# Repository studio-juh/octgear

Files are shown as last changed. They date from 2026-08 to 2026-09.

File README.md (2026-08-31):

# OctGear

RP2040 Zero / compatible boardで動く、8キー + ロータリーエンコーダの小型キーボードです。通常のKeyboard / Consumer Control HIDに加え、WebHIDベースのRemapper、製造検査、ブラウザからのファームウェア更新を提供します。

## Features

- ダイオードなし2 x 4 key matrixと、独立GPIOのロータリーエンコーダCCW / CW / SW
- 8 layers x 11 controlsのキーマップ
- Layer 1-7の個別有効化。Layer 0は常時有効、既定有効はLayer 0/1
- 通常のLayer切り替えは10秒間変化がなければFlashへ保存し、次回起動時に復元
- LayerごとのRGB LED色設定。`0,0,0`で消灯
- Layer色の全灯表示、4灯の点灯パターン、虹色サイクルを切り替えてFlash保存
- 外付けWS2812Bと内蔵mirrorの輝度上限を`0-128`で設定、Flash保存
- 外付けWS2812Bのphysical pixel順を標準／反転で設定、Flash保存
- PCのUSBサスペンド中は外付け・内蔵LEDを消灯
- 打鍵アニメーションを無効／波紋／フラッシュ／スパーク／打鍵虹色から選択、Flash保存
- 通常打鍵は現在Layer色、Layer変更を伴うcontrolは切り替え後のLayer色でアニメーション表示
- Layer表示と独立した打鍵アニメーション輝度上限でコントラストを調整
- Encoder回転方向の反転設定とFlash保存
- PCB v3（Row 1 = GPIO 2）／PCB v2互換（GPIO 0）の切り替えとFlash保存
- Keyboard、Consumer Control、次／前レイヤー、Momentary Layer割り当て
- Next Layerの単押しで次へ進み、同じcontrolのダブルタップで開始位置からPrevious Layerを実行するTap Dance。判定時間は50-1000 msで設定・保存可能（既定250 ms）
- WebHID Remapperによる読込、編集、差分保存
- 物理入力、設定report、Flash保存領域のDiagnostics
- 頒布キット向けの組み立て・Firmware導入・動作確認ガイドと製造データ配布
- WebHIDからのBOOTSEL移行と、同梱UF2の更新
- K1 + K5 + Encoder SWの1秒長押しによる、一時的なWebUSB Remapper案内
- Key 4起動によるREADME drive / Serial rescue。キーマップとdevice設定の確認・変更・初期化に対応

## Web Pages

| Page | Path | Role |
| --- | --- | --- |
| Home | `/` | 製品情報と各ツールへの入口 |
| Start Guide | `/octgear-start.html` | 完成後・完成品購入者向けの導入、設定、サポート案内 |
| Build Guide | `/octgear.html` | 組み立て、Firmware導入、完成検査 |
| Remapper | `/octgear-remapper.html` | キーマップ設定とファームウェア更新 |
| Diagnostics | `/octgear-diagnostics.html` | 出荷前・販売前の個体検査 |

RemapperとDiagnosticsは独立したHTMLとして直接開けます。WebHIDを使うため、対応ブラウザかつsecure contextで実行してください。通常はChromium系ブラウザのHTTPS配信またはlocalhostを想定しています。

## Quick Start

開発環境を初期化します。Arduino CLI、RP2040 core、Arduino librariesはリポジトリ内の`.tools/`と`.arduino/`へ導入されます。

```sh
scripts/setup-dev-env.sh
pnpm dev
```

主な検証・生成コマンド:

```sh
pnpm typecheck          # Web TypeScript
pnpm build              # Web production build
pnpm firmware:build     # Firmware compile
pnpm firmware:web       # Firmware compile + 配信用UF2/RESCUE.CMD/生成日時更新
pnpm hardware:generate  # Hardware profileから3つの生成物を更新
```

初回セットアップと全ビルドをまとめて確認する場合は`scripts/setup-dev-env.sh --verify`を使います。

## Architecture

```text
hardware/octgear/profile.json
        │
        ├─> firmware/.../generated_hardware_config.h
        ├─> apps/web/.../generatedHardwareConfig.ts
        └─> hardware/octgear/pinout.md

Browser ── WebHID config report ──> RP2040 firmware ──> 3-slot Flash journal
   │                                      │
   └─ Remapper / Diagnostics              └─ Keyboard / Consumer HID
```

`hardware/octgear/profile.json`がピン割り当て、コントロール順、レイヤー数の単一ソースです。生成ファイルは直接編集せず、profile変更後に`pnpm hardware:generate`を実行します。Firmware buildでも生成処理は自動実行されます。

詳しいモジュール境界とデータフローは[Architecture](docs/architecture.md)を参照してください。

## Repository Layout

```text
apps/web/                  React + TypeScript + Vite multi-page app
docs/                      横断仕様、開発、運用手順
firmware/octgear/          RP2040 Arduino firmware
hardware/octgear/          Hardware profileと生成pinout
scripts/                   環境構築、生成、firmware build
```

## Hardware Summary

PCB v3を既定とし、RemapperからPCB v2のRow 1配線へ切り替えられます。

現行構成はRow 2本、Column 4本のダイオードなしkey matrixと、A/Common/B/SWを独立GPIOへ接続するロータリーエンコーダです。ダイオードがないため、一部の矩形同時押しは電気的に区別できません。Firmwareは曖昧な間のMatrix状態を更新せず、phantom keyの出力を防ぎます。正確なGPIOは生成された[pinout](hardware/octgear/pinout.md)を参照してください。

通常起動中にK1、K5、Encoder SWを同時に1秒間押すと、LEDが水色に光って再起動し、その起動だけWebUSBのRemapper案内を有効にします。対応するdesktop Chromiumでは接続通知からRemapperを開けます。次回の再起動では通常のUSB構成へ戻ります。

Key 4を押しながらUSB接続すると、その起動だけread-onlyの`OCTGEAR`ドライブとSerial rescueが有効になります。通常起動では表示されません。詳しい操作と復旧手順は[Operations](docs/operations.md)にあります。

## USB Identity

| Field | Default |
| --- | --- |
| Vendor ID | `0x2E8A` |
| Product ID | `0x1133` |
| Manufacturer | `OctGear` |
| Product | `OctGear` |

`0x2E8A:0x1133`は[Raspberry Pi USB PID program](https://github.com/raspberrypi/usb-pid)からOctGear向けに割り当てられたidentityです。Firmware build defaultsとWeb側の接続filterで同じ値を使用します。Forkや別製品ではこの組み合わせを流用せず、各製品で使用許可を得たUSB identityへ置き換えてください。

## Documentation

| Document | 内容 |
| --- | --- |
| [Documentation Index](docs/index.md) | 目的別の文書案内と更新条件 |
| [Architecture](docs/architecture.md) | システム構成、責務、実行時データフロー |
| [Development](docs/development.md) | 環境構築、コマンド、変更別ワークフロー |
| [Operations](docs/operations.md) | Remapper、更新、Diagnostics、Serial rescue |
| [HID Report Protocol](docs/hid-report.md) | WebHID vendor reportのwire format |
| [Cost Estimate](docs/cost-estimate.md) | 少量頒布時の暫定材料原価と梱包条件 |
| [AI Context](docs/ai-context.md) | AI向けのproject map、正本、領域間契約 |
| [Agent Guide](AGENTS.md) | AI agentの作業規約と検証checklist |
| [Web App](apps/web/README.md) | Webアプリ内部の構成 |
| [Firmware](firmware/octgear/README.md) | Firmwareの構成とbuild |
| [Hardware](hardware/octgear/README.md) | Hardware profileと生成物 |

## Distribution And Contact

OctGearの主要頒布先と問い合わせ窓口は[BOOTHショップ](https://hanairo-m.booth.pm/)です。

## Project Policy

OctGearは個人プロジェクトとして管理しています。IssueやPull Requestは送信できますが、確認、返信、レビュー、マージ、対応時期は保証しません。対応まで長期間かかる場合や、対応しない場合があります。必要に応じてForkし、各Forkで管理してください。

## License

Copyright 2026 falxala

Software and software documentation are licensed under the [Apache License 2.0](LICENSE).

`hardware/`以下のhardware design materialsは[OctGear Hardware License 1.0](HARDWARE-LICENSE.md)の対象です。個人による非商用の自作は許可されますが、基準となるハードウェア構成を実質的に変更せず製造・販売することは禁止されています。このため、リポジトリ全体をOSI準拠のオープンソースとして提供するものではありません。

名称、ロゴ、公式性の表示については[Trademark Policy](TRADEMARKS.md)を参照してください。

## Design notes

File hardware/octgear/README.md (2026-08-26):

# OctGear Hardware

The materials in this directory are provided under the [OctGear Hardware License 1.0](../../HARDWARE-LICENSE.md). Personal, non-commercial builds are permitted. Commercial manufacture or sale of the reference hardware without material hardware changes is prohibited.

現行2 x 4 key matrix + rotary encoder版のhardware metadataです。PCB v3を既定とし、同じFirmwareからPCB v2のRow 1配線へ切り替える互換情報も管理します。PCB designそのものではなく、firmwareとWeb UIが共有するlogical control、matrix pin mapping、layer count、default enabled layers、default layer colors、Layer / 打鍵アニメーション輝度既定値 / 上限、打鍵アニメーション既定値、外付けWS2812B GPIO / pixel count / 既定方向を管理します。

## Files

| File | Ownership |
| --- | --- |
| `profile.json` | 手動編集するsingle source of truth |
| `pinout.md` | profileから生成する人向けpin table |
| `../../apps/web/public/build-guide/pcb/` | Build Guide掲載用のPCB製造preview |
| `../../apps/web/public/build-guide/downloads/` | 頒布用Gerber ZIPとcase / knob STL |

同じprofileから次も生成します。

- `firmware/octgear/octgear/generated_hardware_config.h`
- `apps/web/src/products/octgear/generatedHardwareConfig.ts`

## Change Workflow

1. `profile.json`を編集します。
2. Repository rootで`pnpm hardware:generate`を実行します。
3. 3つの生成物のdiffを確認します。
4. Webとfirmwareをbuildします。

```sh
pnpm hardware:generate
pnpm build
pnpm firmware:build
```

Generated filesは直接編集しません。Generatorはindex順とencoder control IDを検証し、不整合時は失敗します。

PCB preview、Gerber、STLはgenerator対象ではありません。製造データを更新した場合はBuild Guideの表示とdownload linkを確認し、Gerber ZIP内のprefixも`octgear-`へ揃えます。

## Electrical Assumptions

- 2 Row x 4 Columnのmatrixで、ダイオードは使用しない
- Columnは`INPUT_PULLUP`、scan対象Rowだけを`OUTPUT LOW`にする
- PCB v3のRow 1はGPIO 2、PCB v2互換のRow 1はGPIO 0。Remapperからrevision単位で切り替え、任意GPIOは指定させない
- ダイオードがないため矩形同時押しは区別できず、Firmwareは曖昧な間のMatrix状態を保持する
- Encoder A/B/SWは`INPUT_PULLUP`、専用Common GPIOは常時`OUTPUT LOW`
- External WS2812Bのdata inputはGPIO 14へ接続し、4 pixels分のdataを送る
- 打鍵アニメーションはmatrixの各columnをLED 1〜4へ対応させ、EncoderのCCW / CW / SWは右端のLED 4をK4 / K8と共有する
- Layer表示は全灯と、4灯の点灯パターンによる8状態をRemapperから切り替えられる
- Status表示は外付けWS2812Bへ出力し、対応boardではonboard WS2812にもミラーする
- LED拡散部品は側面LEDの光を外周へ通す構造のため、透明または半透明の造形素材を推奨する
- OLEDは使用しない
- Key 4は通常inputとrescue boot triggerを兼用

現在のGPIOとfirmware indexは[`pinout.md`](pinout.md)を参照してください。Data flowと影響範囲は[`docs/architecture.md`](../../docs/architecture.md)にあります。

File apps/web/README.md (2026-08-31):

# Web App

React 19 + TypeScript + Viteで構成する、OctGearのWeb toolsです。Home、Start Guide、Build Guide、Remapper、Diagnosticsと、非リンクの印刷用ページをmulti-page buildで出力します。

システム全体の関係は[`docs/architecture.md`](../../docs/architecture.md)、利用手順は[`docs/operations.md`](../../docs/operations.md)を参照してください。

## Entry Points

| Page | HTML | React entry | Page component |
| --- | --- | --- | --- |
| Home | `index.html` | `src/main.tsx` | `src/app/pages/HomePage.tsx` |
| Start Guide | `octgear-start.html` | `src/pages/start-guide.tsx` | `src/app/pages/StartGuidePage.tsx` |
| Start Guide A6 Card | `octgear-start-card-a6.html` | Static HTML | 非リンク・`noindex`の同梱カード印刷用ページ |
| Build Guide | `octgear.html` | `src/pages/build-guide.tsx` | `src/app/pages/BuildGuidePage.tsx` |
| Remapper | `octgear-remapper.html` | `src/pages/remapper.tsx` | `src/app/pages/RemapperApp.tsx` |
| Diagnostics | `octgear-diagnostics.html` | `src/pages/diagnostics.tsx` | `src/app/pages/DiagnosticsApp.tsx` |

GitHub Pages modeではVite baseが`/octgear/`、通常のdevelopment / buildでは`/`です。内部linkとfirmware asset URLはbaseを考慮して組み立てます。

## Source Layout

```text
src/
├── app/
│   ├── components/       pageを構成するUI
│   ├── hooks/            device session lifecycle
│   ├── pages/            page-level stateとworkflow
│   └── remapper/         editor固有の変換
├── features/
│   ├── device/           WebHID transportとcommand codec
│   ├── firmware/         UF2 download / install
│   ├── hardware/         製品共通hardware metadata型
│   └── keymap/           assignment modelとpicker data
├── pages/                multi-page entry points
├── products/             製品定義、製品一覧、製品別generated metadata
└── shared/               i18n等の小さい共通module
```

Dependency directionはpageからfeatureへ向けます。TransportはUI stateを持たず、protocol moduleはDOMを参照しません。特定featureだけで使う処理は`shared`へ移さず、そのfeature内に置きます。

## Product Definitions

`src/products/<product-id>/product.ts`がWeb側の製品単位の正本です。製品名、page route、公式頒布・問い合わせ先、markとBuild Guide asset、USB VID/PID、配布UF2、生成Hardware metadataを1つの`ProductDefinition`へまとめます。Homeは`src/products/catalog.ts`を`ProductCard`で描画し、Remapper、Diagnostics、Build Guideは各entry pointから`ProductProvider`で対象製品を受け取ります。共通のWebHID transportとFirmware updaterは製品固有値を保持しません。

対応製品を追加する場合:

1. `hardware/<product-id>/profile.json`と対応Firmware directoryを用意し、`node scripts/generate-hardware-config.mjs <product-id>`を実行します。
2. `src/products/<product-id>/product.ts`へroute、asset、USB identity、UF2を定義し、`catalog.ts`へ追加します。
3. `ja.ts`と`en.ts`へ製品文言を追加し、`productMessages.ts`で製品IDへ対応づけます。
4. 製品別HTMLと`src/pages/` entryを追加し、`ProductProvider`へ製品定義を渡してVite inputへ登録します。
5. Build Guide assetと配布UF2を製品定義のpublic pathへ配置します。

RemapperとDiagnosticsの共通利用には現在の32-byte WebHID protocolとの互換性が必要です。protocolが異なる製品はtransport / command adapterも製品定義から切り替えられる境界を追加してください。

HomeのOctGear product cardは`public/build-guide/completed/`の正面写真を製品visualとして使用します。Build Guideの完成配置図は`public/build-guide/layout/`のSVG外形へHTML / CSSの8キー、Encoder、側面4灯を重ね、同directoryの完成写真と`public/build-guide/pcb/`のPCB製造previewを併記します。写真とpreviewはページ内で拡大表示できます。部品識別と組み立て工程の写真は`public/build-guide/assembly/`へ配置し、`ja.ts`と`en.ts`の各`photo.file`へfile名を設定するとプレースホルダーから写真表示へ切り替わります。Three.jsのSTL Viewerではケース上面・底面、LED拡散部品、Encoderノブ、ゴム足固定ジグをbrowser内で読み込み、回転・zoom・表示resetを提供します。組み立て、製造データdownload、Firmware導入、Diagnosticsによる完成検査を1ページで案内し、印刷時はnavigationとWeb操作buttonを省略します。

配布用GerberとSTLは`public/build-guide/downloads/`で管理します。公開名には製品名と部品用途を含め、Gerber ZIP内のfile prefixも`octgear-`へ統一します。

## Device Session

接続時は次の順で処理します。

1. 対象entry pointへ渡された製品定義のVID/PID filterでdeviceを選択
2. HID deviceをopen
3. heartbeatを送信
4. `GetState`でdevice dimensions、layer状態、PCBリビジョン、Encoder方向、LEDテープ方向、Layer表示モード、打鍵アニメーションと輝度上限、Tap Dance判定時間を取得
5. `GetKey`で全keymapを読込
6. 300 ms間隔のheartbeatとphysical disconnect listenerを開始

Webは現行Firmwareの14-byte `GetState`と全設定commandを必須契約として扱います。過去Firmware向けの短いresponse、未対応command、Layer色fallbackは受け入れません。

Heartbeat sendが失敗するか700 msでtimeoutするとsessionを閉じます。Firmware側のheartbeat有効期限は3000 msです。

WebHID commandは固定32-byte reportです。同期requestは同じcommand byteのresponseを1つ待つ設計なので、同じtransport上でcommandを並列送信しないでください。詳細は[`docs/hid-report.md`](../../docs/hid-report.md)にあります。

## Remapper State

Remapperは2つのkeymapを保持します。

- `readKeymap`: 最後にdeviceから正常に読んだ内容
- `writeKeymap`: UIで編集中の内容

Layerの有効状態とRGB LED色も読込済みと編集中で分けて保持します。Layer 0は常時有効で、Layer 1-7はcheckboxから変更できます。初期状態ではLayer 0と1だけが有効です。RGB `0,0,0`は消灯として扱います。

Save時はdeviceが返したlayer / key countへnormalizeし、assignment、layer有効状態、RGB色の差分だけを逐次保存します。Readは全keymapとlayer設定を再取得し、編集中内容を置き換えます。Physical `KeyEvent`のpressは現在の表示layerを維持したまま、対応するcontrolだけを選択します。

Read左のoverflow menuから初期化を選ぶと、確認dialogを経て全assignment、layer有効状態、RGB色、PCBリビジョン、Encoder方向、LEDテープ方向、Layer表示モード、打鍵アニメーション、各輝度上限をfirmwareの既定値へ戻し、実機へ保存してからUIを再読込します。

WorkspaceのHardware cardはPCB revisionとcontrol数だけを表示し、「設定を開く」からHardware設定モーダルを開きます。モーダル上部にはBoard詳細を常時表示し、その下に変更可能な設定をまとめます。PCBリビジョンは現行v3（Row 1 = GPIO 2）と旧v2（GPIO 0）だけを選択でき、変更時に即座に実機へ保存・適用します。Encoder方向checkboxも変更時に即座に実機へ保存します。既定値はhardware profileの`encoder.reversed`です。LED輝度上限は`0-128`で編集し、「適用」で実機へ保存します。`0`は消灯、既定値は`32`です。

LEDテープ方向checkboxも変更時に即座に実機へ保存します。標準順は盤面左端のLED 1をphysical pixel 0へ対応させ、反転時は最後のphysical pixelへ対応させます。既定値はhardware profileの`externalRgbLedReversed`です。

Layer表示のプルダウンは、Layer色の全灯、4灯パターン、虹色サイクルを切り替え、変更時に即座に実機へ保存します。4灯パターンはFirmware Layer 0-7を`1000`、`0100`、`0010`、`0001`、`0111`、`1011`、`1101`、`1110`で表示します。虹色サイクルはLayer色の代わりに4灯へ異なる色相を表示して流します。既定値はhardware profileの`statusLedLayerDisplayMode`です。

アニメーション効果のプルダウンは、打鍵時の表示を無効／波紋／フラッシュ／スパーク／打鍵虹色から選び、変更時に即座に実機へ保存します。打鍵虹色は4灯へ異なる色相を表示してLayer表示へ戻します。既定値はhardware profileの`statusLedKeyAnimation`です。

アニメーション輝度上限は`0-128`で編集し、「適用」で実機へ保存します。Layer表示のLED輝度上限とは独立しており、より高い値にすると光っているpixelだけを明るくしてコントラストを強めます。既定値は`96`です。

## Remapper Layout

PCとタブレットでは、topbarの「表示倍率」からWorkspaceを`80%`、`90%`、`100%`へ切り替えられます。既定値は`90%`で、選択値はbrowserのlocal storageへ保存します。倍率はHardware card、Remap、Editor、keyboard pickerへ適用し、Hardware設定モーダルと接続操作は読みやすい通常サイズを保ちます。

段組みは従来の安定したbreakpointを維持し、`1060px`を超える画面では3列、`901-1060px`では2列、`900px`以下では1列で表示します。`640px`以下ではtouch targetを小さくしないため倍率選択を隠し、Workspaceを`100%`で表示します。

## Firmware Updater

`src/features/firmware/firmwareUpdater.ts`は、製品定義からUF2のpublic pathとfile名を受け取り、次を担当します。

- 製品定義の`${BASE_URL}<firmware-public-path>`からのdownload
- File System Access API support判定
- Userが選択したUF2 driveへの製品別UF2 file書込

BOOTSEL移行command自体はdevice featureにあり、page componentがsession closeとUI stateを調停します。

## Localization

`src/shared/i18n/ja.ts`をshapeの基準にし、`en.ts`はその型を満たします。各ページの`Language`ボタンから日本語と英語を即時に切り替えられ、選択値は`studio-juh.locale`としてbrowserのlocal storageへ保存されます。保存値がない場合のdefault localeは`ja`です。表示文言を追加する場合は両方を更新します。

## Development

Repository rootから実行します。

```sh
pnpm dev
pnpm typecheck
pnpm build
```

Firmware bundleを更新する場合は`pnpm firmware:web`を使います。より詳しい変更別手順は[`docs/development.md`](../../docs/development.md)を参照してください。

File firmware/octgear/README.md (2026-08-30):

# OctGear Firmware

RP2040 Arduino coreとAdafruit TinyUSBを使う、現行8キー + rotary encoder版firmwareです。Sketch本体は[`octgear/`](octgear/)にあります。

## Responsibilities

- ダイオードなし2 x 4 key matrixとencoder A/B/SWのscan
- 8 layers x 11 controlsのkeymap解決
- Layer 1-7の有効状態を保存し、layer遷移から無効layerを除外。既定有効はLayer 0/1
- 通常のactive layerを最後の切り替えから10秒後に保存し、次回起動時に復元。Momentary Layerは保存対象外
- LayerごとのRGB LED色を保存。`0,0,0`で消灯
- LEDテープのphysical pixel順を標準／反転で保存
- Layer色の全灯表示、4灯パターンによる8 Layer表示、虹色サイクルを切り替えて保存
- 打鍵アニメーションを無効／波紋／フラッシュ／スパーク／打鍵虹色から選択して保存
- Layer表示と独立した打鍵アニメーション輝度上限を保存
- Keyboard / Consumer Control HID output
- Next Layerの単押しで次へ進み、同じcontrolのダブルタップで開始位置からPrevious Layerを実行するTap Dance。判定時間は50-1000 msで設定・保存可能（既定250 ms）
- WebHID vendor reportによる設定とDiagnostics
- K1 + K5 + Encoder SWの1秒長押しによる、次の1起動だけのWebUSB Remapper案内
- 3-sector Flash journalへのkeymap保存
- UF2 bootloaderへのreboot
- Key 4 boot時のread-only README drive / Serial rescue。全設定の表示、キーマップとdevice設定の変更、既定値への初期化に対応
- GPIO 14の外付けWS2812Bへ、USB未mount時は4 pixelsを流れるカラーホイール、PCのUSBサスペンド中は消灯、Remapper接続時は1秒間のカラーホイール、その後は選択したLayer表示、rescue時は緑を表示。Layer色は200 msで滑らかに遷移し、通常打鍵は現在Layer色、Layer変更を伴うcontrolは切り替え後のLayer色で選択中のアニメーションを重ねる。虹色サイクルと打鍵虹色では4灯へ異なる色相を表示する。対応boardでは内蔵WS2812にも通常表示をミラーする。Layer表示と打鍵アニメーションの輝度上限を個別に`0-128`で保存

通常時は低遅延scanを行い、Remapper / Diagnostics heartbeat中は通常HID出力を抑止します。Rescue boot中も通常HID出力は行いません。

Key matrixにはダイオードがありません。複数Row間で2列以上が同時に導通する曖昧な状態では、scannerは直前の安定したMatrix状態を維持し、phantom keyを出力しません。

### Layer Display Mapping

外付け4灯の通常Layer表示は、全灯、4灯パターン、虹色サイクルをRemapperから切り替えられます。4灯パターンの`1`は現在Layerの設定色、`0`は消灯です。虹色サイクルはLayer色の代わりに4灯へ異なる色相を表示して流します。LEDテープ方向を反転した場合も、表は論理上のLED 1（盤面左端）からLED 4（右端）の順を示します。内蔵LEDは全灯／4灯パターンではLayer色、虹色サイクルでは現在の色相を表示します。

| Firmware Layer | 操作上の順番 | LED 1 → LED 4 |
| ---: | ---: | --- |
| 0 | 1 | `1000` |
| 1 | 2 | `0100` |
| 2 | 3 | `0010` |
| 3 | 4 | `0001` |
| 4 | 5 | `0111` |
| 5 | 6 | `1011` |
| 6 | 7 | `1101` |
| 7 | 8 | `1110` |

### Key Animation Mapping

打鍵アニメーションは物理controlの横位置を4個の側面LEDへ投影します。上下段の同じ列は同じLEDを中心にし、Encoderの回転とswitchは右端のLED 4をK4 / K8と共有します。

| Controls | Animation center |
| --- | --- |
| K1 / K5 | LED 1（pixel 0） |
| K2 / K6 | LED 2（pixel 1） |
| K3 / K7 | LED 3（pixel 2） |
| K4 / K8 / Encoder CCW / CW / SW | LED 4（pixel 3、右端） |

選べる効果は次の5種類です。波紋／フラッシュ／スパークでは、通常controlは現在Layer色、Next / Previous / Momentary Layerなど実際にLayer変更を起こしたcontrolは切り替え後のLayer色をハイライト色として使います。打鍵虹色はLayer色に依存せず、4灯へ異なる色相を表示します。同時打鍵は最大8個まで色と強度を合成します。内蔵LEDは打鍵アニメーションを表示せず通常表示を維持します。

通常表示はLED輝度上限（既定`32`）、打鍵時のハイライトはアニメーション輝度上限（既定`96`）で個別にscaleしてから合成します。アニメーション上限を高くしても光っていないpixelは通常表示側の明るさを維持します。

| Effect | Behavior |
| --- | --- |
| 無効 | 打鍵時もLayer色を維持 |
| 波紋 | ハイライト色の波頭が中心から45 msずつ左右へ進み、各LEDで160 msかけてLayer色へ戻る |
| フラッシュ | 4灯すべてが同時にハイライト色で光り、180 msでLayer色へ戻る |
| スパーク | 押した位置を最も強く、周囲を弱くハイライト色で光らせ、240 msでLayer色へ戻る |
| 打鍵虹色 | 4灯へ異なる色相を同時に表示し、320 msで通常のLayer表示へ戻る。押すたびに開始色相が変わる |

## Build

Repository rootから実行します。

```sh
pnpm firmware:build
pnpm firmware:web
```

既定FQBNは`rp2040:rp2040:waveshare_rp2040_zero`、board optionsは`usbstack=tinyusb,freq=125`です。`pnpm firmware:web`は配信用の次のassetsも更新します。

```text
apps/web/public/firmware/octgear.uf2
apps/web/public/firmware/RESCUE.CMD
apps/web/src/products/octgear/generatedFirmwareMetadata.ts
```

Build scriptsはhardware configとrescue command assetをcompile前に再生成します。環境構築、identity override、検証手順は[`docs/development.md`](../../docs/development.md)を参照してください。

## Configuration

| Configuration | Source |
| --- | --- |
| Matrix GPIO、control / layer count、encoder tuning、default layer colors、Layer表示モード既定値、Layer / 打鍵アニメーション輝度既定値 / 上限、打鍵アニメーション既定値、外付けWS2812B GPIO / pixel count / 既定方向 | `hardware/octgear/profile.json` |
| debounce、scan sleep、Tap Dance判定時間の既定値 / 範囲、LED brightness、heartbeat、WebUSB案内shortcut / device revision、rescue toggle | `octgear/config.h` |
| USB identity defaults | `scripts/compile-firmware.sh`, `scripts/build-web-firmware.sh` |
| HID command IDs / status | `octgear/hid_reports.h` |

Generated headerは直接編集しません。Hardware profile変更後は`pnpm hardware:generate`を実行します。

## Default Keymap

未初期化の保存領域と`ResetConfiguration`では、次のcompile済み既定値を使用します。

| Control | Layer 0 | Layer 1 |
| --- | --- | --- |
| K1 | 次レイヤー | 次レイヤー |
| K2 | Mute | Q |
| K3 | Volume Down | W |
| K4 | Volume Up | E |
| K5 | Momentary Layer 1 | None |
| K6 | Previous Track | A |
| K7 | Play / Pause | S |
| K8 | Next Track | D |
| Encoder CCW | Volume Down | None |
| Encoder CW | Volume Up | None |
| Encoder SW | None | None |

Layer 2〜7は全controlが`None`です。既定で有効なのはLayer 0/1だけで、Layer 0は無効化できません。Encoder方向の既定値はhardware profileの`encoder.reversed`で現行構成は標準、LEDテープ方向の既定値は`externalRgbLedReversed`で現行構成は反転です。写真どおりにLEDテープを配置した新規個体または設定初期化後の個体では、この反転設定によって盤面左端を論理LED 1として扱います。Layer表示の既定値は`statusLedLayerDisplayMode`の全灯、打鍵アニメーションの既定値は`statusLedKeyAnimation`の波紋、アニメーション輝度上限は`statusKeyAnimationBrightness.default`の`96`、Tap Dance判定時間は`250 ms`です。Version 6で保存した設定はFirmware更新だけでは変更されず、初期化したときにこれらの既定値が適用されます。

PCBリビジョンの既定値はv3（Row 1 = GPIO 2）で、RemapperまたはSerial rescueからv2（GPIO 0）へ切り替えられます。旧Firmwareが保存したVersion 6設定はPCB v2互換として読み込み、新規個体または設定初期化後はPCB v3を使います。

## Storage

Keymap、通常のactive layer、layer enable mask、layer RGB colors、各LED輝度上限、Encoder方向、LEDテープ方向、Layer表示モード、打鍵アニメーション、Tap Dance判定時間、PCBリビジョンはexternal SPI Flash上の独立した3つの4KB sectorへ循環保存します。各slotはgenerationとCRCを持ち、起動時はCRCが正常な最新generationを読み込みます。保存中に電源が切れて新slotが不完全になっても、直前の正常slotへfallbackします。

現行storage versionは`6`です。PCBリビジョンは既存headerの未使用flagへ保存するためrecord layoutは変わりません。Version 5以前のslotは移行せず、Version 6 Firmwareでの初回起動時にcompile済み既定値へ初期化します。

標準buildはArduino coreがfilesystem用として扱う64KBをFirmware領域から分離して予約します。Filesystemはmountせず、その先頭12KBをjournalに直接使用します。設定変更時はRAM上の設定全体を次slotへ書き、1回の保存で消去するsectorを1つに限定します。通常Layerの切り替えは10秒間変化がなければ保存し、連続操作を1回の書き込みへまとめます。この間に別の設定を保存した場合は、その書き込みへ現在Layerも含めます。保存形式が無効または未初期化ならcompile済みdefaultで初期化します。

Diagnostics / Serial rescueのstorage self-testはtest patternのwrite、readback、元keymapのrestoreを行います。Test patternのslotは通常journalと異なるmagicを持ち、復元前に電源が切れても通常起動では読み込みません。実Flashへ書くため、必要な検査時だけ実行します。

## Further Reading

- [Firmware module map](octgear/README.md)
- [Architecture](../../docs/architecture.md)
- [HID report protocol](../../docs/hid-report.md)
- [Update, diagnostics, and rescue](../../docs/operations.md)

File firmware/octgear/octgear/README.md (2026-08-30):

# Firmware Sketch

Arduino IDE / Arduino CLIで開くOctGear firmware sketchです。利用者向けの更新・救済手順は[`docs/operations.md`](../../../docs/operations.md)、system全体のflowは[`docs/architecture.md`](../../../docs/architecture.md)を参照してください。

## Files

| File | Role |
| --- | --- |
| `octgear.ino` | `setup()` / `loop()`とmode調停 |
| `config.h` | timing、LED、heartbeat、WebUSB案内、rescue設定 |
| `generated_hardware_config.h` | profileから生成したpin / count定数 |
| `key_scanner.*` | 2 x 4 matrix scan、debounce、encoder decode |
| `keymap.*` | default keymap、RAM assignment、active layer |
| `keymap_storage.*` | 3-sector Flash journalのload / save / CRC / self-test |
| `key_assignment.*` | assignment typeとconstructor |
| `hid_device.*` | USB HID、config command、layer action |
| `hid_output_queue.*` | Keyboard押下状態の6KRO集約、Consumer優先制御、report retry queue |
| `hid_report_descriptor.*` | TinyUSB HID report descriptor |
| `hid_reports.h` | report ID、command、status enum |
| `readme_drive.*` | Rescue boot用read-only FAT12 drive |
| `serial_rescue.*` | Rescue boot用command parser |
| `status_led.*` | Device state表示 |
| `webusb_landing.*` | 1回限りのWebUSB landing bootと物理shortcut |
| `rescue.cmd` | Windows offline rescue client source |
| `rescue_cmd_asset.h` | `rescue.cmd`から生成するembedded asset |

## Setup And Loop

`setup()`はLED、keymap、scannerを初期化し、watchdog scratchのWebUSB landing flag、Key 4のRescue boot状態の順に判定してからUSB deviceを開始します。Landing flagがある起動ではUSB device revisionを`0x0101`へ変更してWindowsのdescriptor cacheを通常起動と分離し、Rescue判定を抑止します。

`loop()`はscanner、通常HID送信、config report、Serial rescue、status LEDを順に更新します。Remapperまたはrescueがactiveな間は通常HID出力を止め、長いscan sleepへ切り替えます。PCがUSBをサスペンドしている間は外付け・内蔵status LEDを消灯し、resume後は現在Layerの表示へ戻します。

## Timing

`config.h`の主なtuning値:

| Setting | Default | Purpose |
| --- | ---: | --- |
| `DEBOUNCE_US` | `5000` | Matrix key / encoder SW debounce |
| `IDLE_SCAN_SLEEP_US` | `100` | 通常modeのscan間sleep |
| `REMAPPER_SCAN_SLEEP_US` | `1000` | Config / rescue modeのscan間sleep |
| `REMAPPER_HEARTBEAT_TIMEOUT_MS` | `3000` | 通常出力抑止を解除する期限 |
| `DEFAULT_LAYER_TAP_DANCE_TERM_MS` | `250` | Next Layerの単押し確定とダブルタップ判定の既定時間。Remapperから50-1000 msで設定・保存可能 |
| `ACTIVE_LAYER_SAVE_DELAY_MS` | `10000` | 通常Layer切り替え後の遅延保存時間 |
| `WEBUSB_LANDING_HOLD_MS` | `1000` | K1 + K5 + Encoder SWで案内modeへ入る長押し時間 |
| `WEBUSB_LANDING_ACK_MS` | `200` | 再起動前の水色LED acknowledgement時間 |
| `STATUS_LAYER_TRANSITION_MS` | `200` | Layer色を切り替えるフェード時間 |
| `STATUS_LED_FRAME_MS` | `20` | Layer色フェードの更新間隔 |
| `STATUS_KEY_RIPPLE_STEP_MS` | `45` | 打鍵波紋が隣のLEDへ進む間隔 |
| `STATUS_KEY_RIPPLE_PULSE_MS` | `160` | 各LEDの打鍵波紋が減衰する時間 |
| `STATUS_KEY_FLASH_MS` | `180` | 全灯フラッシュが減衰する時間 |
| `STATUS_KEY_SPARK_MS` | `240` | 局所スパークが減衰する時間 |
| `STATUS_KEY_RAINBOW_MS` | `320` | 打鍵虹色が通常表示へ戻る時間 |
| `STATUS_REMAPPER_ANIMATION_MS` | `1000` | Remapper接続時のカラーホイール表示時間 |
| `CONFIG_RESPONSE_READY_RETRIES` | `20` | Config input reportのHID ready retry |
| `CONFIG_RESPONSE_RETRY_DELAY_US` | `100` | Retry間隔 |

Input latencyを調整する場合はdebounceとidle sleepの両方を考慮します。Encoder detentは`config.h`ではなくhardware profileの`stepsPerDetent`で調整します。Encoder A/Bで両bitが同時に変わる不正遷移やdetentへ戻った不完全なcycleは破棄し、次のdetentを新しい起点として再同期します。

## Build Invariants

- `usbstack=tinyusb`が必要です。Vendor reportとcomposite USB deviceが依存します。
- CPU frequencyは125 MHzに固定します。
- 2MB Flashの末尾に64KBの保存領域を予約します。標準scriptの`flash=2097152_65536`を外さないでください。
- `generated_hardware_config.h`と`rescue_cmd_asset.h`はsourceを変更後に再生成します。
- HID protocolを変更する場合はWeb implementationと[`docs/hid-report.md`](../../../docs/hid-report.md)を同時に更新します。
- Storage layoutを変える場合は既存deviceのmigrationまたは明示的な初期化方針が必要です。

Storageは3つの4KB sectorを循環し、各slotへheader、generation、全layerのassignment records、1-byteのlayer有効mask、3 bytes x layerのRGB色、Encoder方向・LEDテープ方向・Layer表示モード・打鍵アニメーションを持つ1-byteのdevice flags、Layer / アニメーション輝度上限、通常のactive layer、16-bitのTap Dance判定時間、CRC32を固定順で保存します。Layer 0は常時有効です。現行Version 6は旧versionを移行せず、起動時にVersion 6としてCRCが正常な最新generationを選びます。有効なslotがない場合はhardware profileとcompile済みkeymapの既定値から最初のslotを作成します。

Repository rootからの標準buildは`pnpm firmware:build`です。直接Arduino CLIを呼ぶ場合も、先に必要な生成処理を実行してください。

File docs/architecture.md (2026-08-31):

# Architecture

OctGearは、hardware profile、RP2040 firmware、Webアプリの3領域で構成されます。FirmwareとWebはvendor-defined HID reportを境界に独立し、hardware profileから共有すべき定数だけを生成します。

## System Context

```text
                        ┌──────────────────────────────┐
                        │ Browser                      │
                        │ Home / Guide / Remapper / Diag│
                        └──────────────┬───────────────┘
                                       │ WebHID report ID 3
                                       │ 32-byte input/output
                        ┌──────────────▼───────────────┐
Physical controls ─────>│ RP2040 firmware              │─────> Keyboard HID
2x4 matrix + encoder    │ scan / keymap / HID / storage│─────> Consumer HID
                        └──────────────┬───────────────┘
                                       │ 3-slot journal / CRC
                        ┌──────────────▼───────────────┐
                        │ External SPI Flash           │
                        │ persisted keymap             │
                        └──────────────────────────────┘
```

通常動作ではfirmwareだけで入力を処理します。RemapperまたはDiagnosticsがheartbeatを送っている間は、設定中の物理入力がOSへ漏れないようKeyboard / Consumer出力を抑止し、代わりに`KeyEvent`をWebへ送ります。

## Source Of Truth

`hardware/octgear/profile.json`は次の値の単一ソースです。

- Matrix Row / Columnと各物理キー位置
- エンコーダのGPIO、方向、1 detentあたりのstep数
- firmware indexとWeb UI上のcontrol順
- layer count、physical key count、control count
- default enabled layers
- default layer RGB colors
- 外付けWS2812Bのpixel count、既定方向、Layer / 打鍵アニメーション輝度上限、打鍵アニメーション既定値

`scripts/generate-hardware-config.mjs`がprofileを検証し、次の3ファイルを生成します。

| Generated file | Consumer |
| --- | --- |
| `firmware/octgear/octgear/generated_hardware_config.h` | Firmware compile-time constants |
| `apps/web/src/products/octgear/generatedHardwareConfig.ts` | Web UIのcontrol metadata |
| `hardware/octgear/pinout.md` | 人が読むpinout |

生成スクリプトはMatrix Row / Columnとキーのindex・範囲、PCB v3 / v2互換の各pin構成におけるGPIO重複、encoder controlが`enc-ccw`、`enc-cw`、`enc-sw`の順で連続することを検証します。生成物は直接編集しません。

## Firmware Modules

Firmware entry pointは`firmware/octgear/octgear/octgear.ino`です。

| Module | Responsibility |
| --- | --- |
| `config.h` | timing、LED、heartbeat、WebUSB案内、rescue等の手動設定 |
| `generated_hardware_config.h` | profile由来のpin / count定数 |
| `key_scanner.*` | PCBリビジョンに応じたMatrix scan / debounce、quadrature decode、control mask生成 |
| `keymap.*` | RAM上のassignment、active layer、layer RGB color、PCBリビジョン、Encoder方向、LEDテープ方向、Layer表示モード、打鍵アニメーションと輝度上限 |
| `keymap_storage.*` | 3-sector Flash journalのload / save / CRC / self-test |
| `key_assignment.*` | assignmentの型とconstructor |
| `hid_device.*` | USB lifecycle、config command、通常HID出力の調停 |
| `hid_output_queue.*` | 押下中入力の集約、Consumer優先順位、HID ready待ち中reportの保持 |
| `hid_report_descriptor.*` | Keyboard、Consumer、vendor report descriptor |
| `readme_drive.*` | rescue boot時のread-only FAT12 MSC |
| `serial_rescue.*` | rescue boot時の115200 baud command interface |
| `status_led.*` | USB未mount時に流れるカラーホイール、USBサスペンド中の消灯、Remapper接続直後1秒のカラーホイール、layer、選択式打鍵アニメーション、rescue状態の表示 |
| `webusb_landing.*` | 物理shortcut、watchdog scratchによる1回限りのboot flag、WebUSB landing descriptor |

### Main Loop

1. Scannerが8物理キーとencoder SWを読み、encoder A/Bの有効なGray-code遷移を回転eventへ変換します。不正遷移や不完全なcycleは次のdetent境界で再同期し、途中のcountを後続の回転へ持ち越しません。
2. K1 + K5 + Encoder SWの同時押しをsystem shortcutとして先に判定し、それ以外の通常control mask差分を`sendKeyChanges()`へ渡します。
3. `hid_device`がassignmentを解決し、Keyboard / Consumer reportまたはlayer変更を処理します。
4. Config report受信、queued HID report、USB suspend / remote wakeupを更新します。
5. 状態LEDを更新し、通常時100 us、config mode時1000 us sleepします。

Encoder CCW / CWは保持状態ではなく、1 clickのpress pulseとしてindex 8 / 9に現れます。Encoder SWはindex 10の通常debounced inputです。

Key matrixはダイオードなしです。複数Rowが2列以上を共有する矩形同時押しは実際の押下とghostを区別できないため、scannerは曖昧さが解消するまで直前の安定したMatrix状態を保持します。

### Layer Semantics

Assignmentは`None`、`Keyboard`、`Consumer`、`LayerCycle`、`MomentaryLayer`、`LayerPrevious`の6種類です。

- Layer 0は常時有効で、Layer 1-7の有効状態はFlashへ保存します。既定有効maskはLayer 0/1です。
- `LayerCycle`は最初の押下を設定されたTap Dance判定時間だけ保留し、単押しなら有効なlayerだけを次方向へ循環します。判定時間は50-1000 ms、既定250 msでFlashへ保存します。同じ物理controlを期限内に再度押すと保留した次方向への遷移を破棄し、開始位置から`LayerPrevious`相当として前方向へ循環します。別controlの押下で中断された場合は、保留した次方向への遷移を先に確定してから移動先layerのassignmentを解決します。
- `LayerPrevious`は有効なlayerだけを前方向へ循環します。
- `MomentaryLayer`はtarget layerが有効な場合だけ押下中に切り替え、releaseで通常layerへ戻ります。
- 通常のactive layerは最後の切り替えから10秒間変化がなければFlashへ保存し、次回起動時に復元します。連続切り替えでは保存期限を延長し、Momentary Layerは保存しません。
- Keyboard assignmentはmodifier bitmapと最大6 keycodesを持ちます。
- Consumer assignmentは16-bit usageを1つ持ちます。
- 押下中のKeyboard assignmentは単一の6KRO reportへ統合し、modifierはOR、keycodeは重複を除いて送ります。6種類を超える場合はErrorRollOverを送ります。
- Consumer assignmentは最後に押された押下中キーを優先し、そのキーを離すと一つ前の押下中usageへ戻ります。Encoder CCW / CWだけはdetentごとのtapとして送ります。
- Layer colorはRGB各8-bitで、`0,0,0`を消灯としてFlashへ保存します。外付け4灯はLayer色の全灯表示、8 Layerを識別する点灯パターン、流れる虹色サイクルを切り替えられます。

Compile済みdefault keymapはLayer 0/1だけにassignmentを持ち、Layer 2-7は全controlが`None`です。具体的な割り当ては[Firmware Default Keymap](../firmware/octgear/README.md#default-keymap)を参照してください。

起動時はcompile済みdefault keymap、layer設定、Encoder方向、LEDテープ方向、Layer表示モード、打鍵アニメーション、各輝度上限をRAMへ作成してから保存領域を読みます。保存済みの通常Layerが有効なら、そのLayerをactiveにして開始します。保存領域のmagic、version、layer数、key数、record sizeのいずれかが一致しない場合は、現在のdefault設定を保存して初期化します。

## Web Modules

Web entry pointはページごとに分かれ、共通実装を`src/app`と`src/features`から利用します。

| Path | Responsibility |
| --- | --- |
| `src/pages/*.tsx` | Vite multi-page entry points |
| `src/app/pages/` | Home、Start Guide、Build Guide、Remapper、Diagnosticsの画面状態とworkflow |
| `src/app/components/` | UI panelとkeycap表示 |
| `src/app/hooks/useDeviceSession.ts` | heartbeat、timeout、disconnect cleanup |
| `src/features/device/` | WebHID transport、protocol encode/decode、device commands |
| `src/features/keymap/` | assignment model、normalize、picker option |
| `src/features/hardware/` | profileから生成したUI metadata |
| `src/features/firmware/` | UF2 download / File System Access API書込 |
| `src/products/` | 製品ごとのroute、asset、USB identity、UF2、hardware metadataと製品一覧 |
| `src/shared/i18n/` | 日本語・英語message。現在のdefaultは日本語 |

`WebHidTransport`は1 device / 1 in-flight commandを前提とします。同期commandはcommand byteが一致する最初のinput reportを待ち、1秒でtimeoutします。`KeyEvent`は別listenerで非同期に購読します。

## Runtime Flows

### Connect And Read

1. 各entry pointから注入された製品定義の`0x2E8A:0x1133` filterでdevice pickerを開きます。
2. Deviceをopenし、最初のheartbeatを送ります。
3. `GetState`でfirmwareのlayer / key countを取得します。
4. `GetKey`をlayer x key分、`GetLayerColor`をlayer分送って全設定を読みます。
5. Webは300 ms間隔でheartbeatを送り、失敗または700 ms timeout時にdisconnect扱いにします。

### Edit And Save

Webは最後に読んだkeymap / layer mask / RGB colorsと、編集中の値を別に保持します。Save時にdeviceが報告した範囲へnormalizeし、変更したlayer設定、色、assignmentだけを順に保存します。同一内容はFlashへ書きません。

### Rescue Boot

起動時にKey 4がLOWならread-onlyの`OCTGEAR` MSCとSerial rescueを有効にします。このmodeでは通常HID出力を行わず、LEDを弱い緑で表示します。USBを抜いて通常接続すると終了します。

### WebUSB Landing Boot

通常起動中にK1、K5、Encoder SWを1秒間保持すると、通常入力をreleaseして水色のLED acknowledgementを表示し、watchdog scratch 0/1へmagicと反転値を書いてwarm rebootします。`setup()`はflagを消去し、USB device revisionを通常の`0x0100`から案内用`0x0101`へ変更してから、WebUSB interfaceとRemapper landing URLを追加します。revisionを分けることで、Windowsが通常構成のdescriptor cacheを案内起動へ流用することを避けます。この起動では通常HID / WebHIDを維持し、Rescue boot判定を抑止します。Rescue triggerはshortcutに含まれないK4です。flagはFlashへ保存しないため、次の再起動は通常のUSB構成です。

## Cross-System Contracts

次の変更は複数領域へ影響します。

| Change | Required checks |
| --- | --- |
| GPIO / control数 / encoder | profile更新、generate、Web build、firmware build |
| HID command / payload | firmware `hid_reports.h`とhandler、Web protocol、`docs/hid-report.md` |
| Assignment kind | firmware model、Web model / UI、storage format、protocol docs |
| USB VID/PID | firmware build env、Web filter、READMEのidentity |
| Rescue script | `rescue.cmd`更新、asset生成、firmware / Web bundle更新 |

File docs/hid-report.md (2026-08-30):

# HID Report Protocol

WebHID版Remapper / Diagnosticsで使う固定長の設定用reportです。この文書はfirmwareの`hid_reports.h` / `hid_device.cpp`とWebの`hidProtocol.ts` / `deviceCommands.ts`の境界仕様です。

通常のキーボード/Consumer Control HID reportとは別に、vendor-defined reportを1つ持ちます。

## Report

| Field | Value |
| --- | --- |
| Report ID | `3` |
| Direction | Web -> device: Output report |
| Direction | Device -> Web: Input report |
| Size | `32 bytes` |

WebHIDの `sendReport(reportId, data)` では、`reportId` は引数で渡すため、`data[0]` はcommandです。

Multi-byte integerはlittle-endianです。未使用byteは送信側で`0`にします。Webは現行Firmwareが定義するpayload lengthを厳密に検証し、過去の短いresponseや未知のenum値は受け入れません。

## Request Layout

```text
byte 0      command
byte 1..31  command payload
```

## Response Layout

```text
byte 0      command
byte 1      status
byte 2      payload length
byte 3..31  response payload
```

## Status

| Value | Name | Meaning |
| ---: | --- | --- |
| `0x00` | `Ok` | Success |
| `0x01` | `InvalidLength` | Request payload is too short |
| `0x02` | `OutOfRange` | Layer or key index is invalid |
| `0x03` | `StorageError` | Device could not persist the updated assignment |
| `0x04` | `Unsupported` | Command is not supported on this MCU/firmware build |
| `0xff` | `UnknownCommand` | Command is not supported |

## Commands

| Value | Name | Request payload | Response payload |
| ---: | --- | --- | --- |
| `0x01` | `GetState` | none | `activeLayer, layerCount, keyCount, matrixRowCount, enabledLayerMask, encoderReversed, statusLedBrightness, statusLedReversed, statusKeyAnimation, statusKeyAnimationBrightness, statusLayerDisplayMode, layerTapDanceTermMs[2], pcbRevision` |
| `0x02` | `SetLayer` | `layer` | `layer` |
| `0x03` | `GetKey` | `layer, keyIndex` | key assignment payload |
| `0x04` | `SetKey` | key assignment payload | `layer, keyIndex` |
| `0x05` | `EnterBootloader` | none | none, then reboot to UF2 bootloader |
| `0x06` | `RemapperHeartbeat` | none | no response |
| `0x07` | `KeyEvent` | not supported | `layer, keyIndex, pressed` |
| `0x08` | `DiagnosticReport` | `0x43, 0x59, 0x42, 0x38` | `0x52, 0x50, 0x54, version, echoed request bytes[4]` |
| `0x09` | `DiagnosticStorage` | none | `ok, layerCount, keyCount` |
| `0x0a` | `SetLayerEnabled` | `layer, enabled` | `layer, enabled, activeLayer, enabledLayerMask` |
| `0x0b` | `GetLayerColor` | `layer` | `layer, red, green, blue` |
| `0x0c` | `SetLayerColor` | `layer, red, green, blue` | `layer, red, green, blue` |
| `0x0d` | `PreviewLayerColor` | `layer, red, green, blue` or `0xff` | previewed values or none |
| `0x0e` | `ResetConfiguration` | none | `activeLayer, enabledLayerMask` |
| `0x0f` | `SetEncoderReversed` | `reversed` | `reversed` |
| `0x10` | `SetStatusLedBrightness` | `brightness` | `brightness` |
| `0x11` | `SetStatusLedReversed` | `reversed` | `reversed` |
| `0x12` | `SetStatusKeyAnimation` | `animation` | `animation` |
| `0x13` | `SetStatusKeyAnimationBrightness` | `brightness` | `brightness` |
| `0x14` | `SetStatusLayerDisplayMode` | `mode` | `mode` |
| `0x15` | `SetLayerTapDanceTerm` | `termMs[2]` | `termMs[2]` |
| `0x16` | `SetPcbRevision` | `revision` | `revision` |

通常の同期commandは、requestと同じcommandをbyte 0に持つresponseを1つ返します。`RemapperHeartbeat`と`EnterBootloader`は例外です。Heartbeatは応答を返さず、bootloader commandはdeviceが再起動するためresponseを待ちません。

`KeyEvent` is an asynchronous device-to-Web input report. The firmware emits it when a physical key, encoder rotation, or encoder switch press is detected while the remapper heartbeat is active. Remapper uses `keyIndex` to select the matching control and ignores `layer`, keeping the layer currently shown in the UI.

`RemapperHeartbeat` is sent periodically by Remapper and Diagnostics. While the heartbeat is active, normal keyboard / consumer output is suppressed by firmware.

`DiagnosticReport` is a synchronous send/receive self-test for Diagnostics. The Web UI sends a fixed nonce and verifies that the firmware returns the `RPT` signature plus the same nonce.

`DiagnosticStorage` writes a test pattern through the same three-slot Flash journal used by normal remapping, reads it back, verifies it, and restores the original keymap. Run it only when needed because the test and restore each consume a journal write.

`enabledLayerMask`はbit indexをlayer indexとして使います。Bit 0は常に`1`です。`SetLayerEnabled`でLayer 0を無効にするrequestは`OutOfRange`になります。Active layerを無効にするとfirmwareはLayer 0へ戻ります。`SetLayer`とMomentary Layerは無効layerへ遷移せず、Layer Cycleは無効layerをskipします。

`SetLayer`、Layer Cycle、Previous Layer、Serial rescueで変更した通常のactive layerは、最後の切り替えから10秒後にFlashへ保存され、次回起動時に復元されます。Momentary Layerは保存対象外です。

Layer colorの各channelは`0-255`です。RGBがすべて`0`の場合、通常modeのLayer LEDを消灯します。

`PreviewLayerColor`はFlashやRAM上のlayer設定を変更せず、Remapper接続中のLED表示だけを一時的に上書きします。`layer = 0xff`のrequest、`SetLayer`、または成功した`SetLayerColor`でpreviewを解除します。WebHID output reportは常に32 bytesのため、payload lengthではなく予約layer値で解除を明示します。Heartbeatが途切れた場合も通常のactive layer表示へ戻ります。

`encoderReversed`と`reversed`は`0`がprofileの配線どおり、`1`がA/Bの回転eventを反転した状態です。`SetEncoderReversed`は変更をFlashへ即座に保存します。

`statusLedBrightness`と`SetStatusLedBrightness`の`brightness`は`0-128`です。`0`は消灯、既定値は`32`です。変更はFlashへ即座に保存し、通常のLayer表示、カラーホイール、rescue表示、内蔵mirrorへ適用します。

`statusLedReversed`と`SetStatusLedReversed`の`reversed`は、`0`がLED 1をphysical pixel 0へ対応させる標準順、`1`がLED 1を最後のphysical pixelへ対応させる反転順です。変更はFlashへ即座に保存し、USB未mount時の流れるカラーホイールと位置依存の打鍵アニメーションへ適用します。

`statusKeyAnimation`と`SetStatusKeyAnimation`の`animation`は、`0`が波紋、`1`が無効、`2`が全灯フラッシュ、`3`が押下位置中心のスパーク、`4`が4灯へ異なる虹色を表示して320 msでLayer表示へ戻る打鍵虹色です。変更はFlashへ即座に保存します。

`statusKeyAnimationBrightness`と`SetStatusKeyAnimationBrightness`の`brightness`は`0-128`です。既定値は`96`で、通常打鍵の現在Layer色ハイライトとLayer変更時の切り替え後Layer色ハイライトに適用します。Layer側の`statusLedBrightness`より高く設定すると、光っていないpixelの明るさを変えずにコントラストを強められます。`0`ではアニメーション効果を選択したままハイライトだけを消せます。変更はFlashへ即座に保存します。

`statusLayerDisplayMode`と`SetStatusLayerDisplayMode`の`mode`は、`0`が全灯、`1`が4灯パターン、`2`が虹色サイクルです。4灯パターンはFirmware Layer 0-7をLED 1から4の順に`1000`、`0100`、`0010`、`0001`、`0111`、`1011`、`1101`、`1110`で表示します。`1`のpixelには現在Layerの色を使います。虹色サイクルはLayer色の代わりに4灯へ異なる色相を表示し、連続して流します。変更はFlashへ即座に保存します。

`layerTapDanceTermMs`と`SetLayerTapDanceTerm`の`termMs`はlittle-endianの16-bit値です。設定範囲は`50-1000 ms`、既定値は`250 ms`です。Next Layerの単押し確定と同じcontrolのダブルタップ判定の両方に使い、変更はFlashへ即座に保存します。Storage version 6でfieldを追加しており、旧storage versionは移行せず既定設定へ初期化します。

`pcbRevision`と`SetPcbRevision`の`revision`は`3`が現行PCB（Matrix Row 1 = GPIO 2）、`2`が旧PCB（Matrix Row 1 = GPIO 0）です。任意GPIOは指定できません。変更はFlashへ即座に保存され、scannerを再初期化するため再起動は不要です。未初期化時と設定初期化時はPCB v3、既存のVersion 6保存slotで未使用だったflagが`0`の個体はPCB v2互換として読み込みます。

`ResetConfiguration`は全assignment、layer有効mask、layer RGB色、LED輝度上限、Encoder方向、LEDテープ方向、Layer表示モード、打鍵アニメーション、アニメーション輝度上限、Tap Dance判定時間、PCBリビジョンをcompile済みの既定値へ戻し、保存領域全体へ書き込みます。Active layerと次回起動LayerはLayer 0へ戻ります。

## Session Lifecycle

Webは接続直後に`RemapperHeartbeat`を送り、`GetState`、全`GetKey`の順にdevice stateを読みます。その後は300 ms間隔でheartbeatを送ります。Firmwareは最後のheartbeatから3000 ms以内をremapper activeとみなし、その間は通常のKeyboard / Consumer outputを抑止して`KeyEvent`を有効にします。

Web transportは同期requestごとに同じcommand byteのresponseを待ち、既定1000 msでtimeoutします。同じcommandを含む複数requestを並列化するとresponseを識別できないため、commandは逐次送信します。現在のprotocolにtransaction IDはありません。

Physical disconnectまたはheartbeat failure時、WebはHID deviceをcloseして未接続状態へ戻ります。Heartbeatが止まったfirmwareはtimeout後に通常HID outputへ戻ります。

## Key Indexes

Current firmware reports `keyCount = 11`.

| Index | Control |
| ---: | --- |
| `0..7` | Physical keys 1-8 |
| `8` | Encoder CCW rotation |
| `9` | Encoder CW rotation |
| `10` | Encoder SW |

## Key Assignment Payload

`GetKey` response and `SetKey` request use the same assignment shape.

```text
byte 0      layer
byte 1      keyIndex
byte 2      kind
byte 3      modifier
byte 4..9   keyboard keycodes[6]
byte 10     consumer usage low byte
byte 11     consumer usage high byte
byte 12     target layer
```

`target layer` is used when `kind` is `MomentaryLayer`; otherwise it is `0`.

Keyboard assignmentはmodifier bitmapと6-key rollover slotsを使用します。Consumer usageとtarget layerはkindに応じてnormalizeされ、使用しないfieldは`0`です。

`kind` values:

| Value | Name |
| ---: | --- |
| `0` | None |
| `1` | Keyboard |
| `2` | Consumer |
| `3` | LayerCycle |
| `4` | MomentaryLayer |
| `5` | LayerPrevious |

`LayerCycle`は有効layerを次方向へ、`LayerPrevious`は前方向へ循環します。どちらもLayer 0からwrapします。`LayerCycle`の最初の押下は設定されたTap Dance判定時間だけ保留され、単押しなら次方向へ進みます。同じ物理controlを期限内に再度押すと保留した遷移を破棄し、開始位置から`LayerPrevious`相当として処理します。assignment kindとwire formatは変わりません。

## Current Contract

- Webは14-byteの`GetState` responseと、この文書にある全commandを実装した現行Firmwareだけを対象にします。
- Webは`GetState`が返す`layerCount`、`keyCount`、`enabledLayerMask`をdeviceの書込可能範囲とlayer状態として使います。
- 未知のassignment kind、LED mode、payload lengthはprotocol errorとして扱います。FirmwareとWebのencode / decode / validationは常に同時に更新します。
- Report sizeまたはReport IDを変更する場合はTinyUSB descriptor、firmware buffer、Web codecを同時に変更します。
- Storage formatはwire protocolとは別契約ですが、頒布前は現行versionだけを読み、旧version migrationは提供しません。

## Implementation References

| Side | Files |
| --- | --- |
| Firmware enums / descriptor | `firmware/octgear/octgear/hid_reports.h`, `hid_report_descriptor.cpp` |
| Firmware command handling | `firmware/octgear/octgear/hid_device.cpp` |
| Web report codec | `apps/web/src/features/device/hidProtocol.ts` |
| Web command API | `apps/web/src/features/device/deviceCommands.ts` |
| Web transport / timeout | `apps/web/src/features/device/webHidTransport.ts` |

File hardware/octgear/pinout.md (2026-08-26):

# Pinout

現行8キー + ロータリーエンコーダ版のファームウェアとPCB設計を合わせるためのピン割り当てです。

この表は `hardware/octgear/profile.json` から生成します。既定はPCB v3です。RemapperまたはSerial rescueからPCB v2互換へ切り替えられます。

## Key Matrix

8 keys form a 2 x 4 matrix without diodes. Columns use `INPUT_PULLUP`; firmware drives only the selected row `OUTPUT LOW` and leaves the other row high impedance.

| Logical key | Firmware index | Matrix position | Notes |
| --- | ---: | --- | --- |
| Key 1 | 0 | Row 1 / Column 1 | Matrix Row 1 / Column 1 |
| Key 2 | 1 | Row 1 / Column 2 | Matrix Row 1 / Column 2 |
| Key 3 | 2 | Row 1 / Column 3 | Matrix Row 1 / Column 3 |
| Key 4 | 3 | Row 1 / Column 4 | Matrix Row 1 / Column 4 / README drive trigger |
| Key 5 | 4 | Row 2 / Column 1 | Matrix Row 2 / Column 1 |
| Key 6 | 5 | Row 2 / Column 2 | Matrix Row 2 / Column 2 |
| Key 7 | 6 | Row 2 / Column 3 | Matrix Row 2 / Column 3 |
| Key 8 | 7 | Row 2 / Column 4 | Matrix Row 2 / Column 4 |

| Row | Index | PCB v3 GPIO | PCB v2 GPIO | Mode |
| --- | ---: | ---: | ---: | --- |
| Row 1 | 0 | 2 | 0 | Scan output; selected row is OUTPUT LOW |
| Row 2 | 1 | 9 | 9 | Scan output; selected row is OUTPUT LOW |

| Column | Index | GPIO | Mode |
| --- | ---: | ---: | --- |
| Column 1 | 0 | 5 | INPUT_PULLUP |
| Column 2 | 1 | 6 | INPUT_PULLUP |
| Column 3 | 2 | 7 | INPUT_PULLUP |
| Column 4 | 3 | 8 | INPUT_PULLUP |

Because the matrix has no diodes, rectangular multi-key combinations are electrically ambiguous. Firmware holds the previous stable matrix state while an ambiguous combination is present, preventing phantom key output.

## Rotary Encoder

Encoder A/B and SW are independent from the key matrix. A/B/SW use `INPUT_PULLUP`; Common is a dedicated `OUTPUT LOW` on GPIO 12.

The compiled default direction is standard. Remapper can change and persist the direction without rebuilding firmware.

| Signal | GPIO | Firmware control index |
| --- | ---: | ---: |
| A | 11 | CCW/CW: 8/9 |
| Common | 12 | - |
| B | 13 | CCW/CW: 8/9 |
| SW | 10 | 10 |

## Status LED

外付けWS2812Bのdata inputをGPIO 14へ接続します。Firmwareは4 pixels分のdataを送り、layer、打鍵アニメーション、Remapper、rescue状態を表示します。論理上はLED 1を盤面左端として扱い、物理pixel順の既定値は反転です。物理キーの打鍵アニメーションはmatrix columnに対応し、EncoderのCCW / CW / SWは論理上の右端LEDへ割り当てます。Remapperから向き、Layer表示モード、打鍵アニメーション効果を変更して保存できます。Layer表示モードの既定値は全灯です。Boardに内蔵WS2812がある場合はlayer色をミラーします。Layer表示の輝度上限は0-128で既定値32、打鍵アニメーションの輝度上限は0-128で既定値96です。

| Signal | GPIO | Pixels | Mode |
| --- | ---: | ---: | --- |
| WS2812B DIN | 14 | 4 | 800 kHz GRB data |

## Removed Parts

- OLED

OLEDは使用しません。

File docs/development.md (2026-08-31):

# Development

この文書はlocal setup、日常的な変更、生成物、検証の手順をまとめます。コマンドはすべてrepository rootで実行します。

## Prerequisites

- Linux x86_64 / arm64、またはmacOS x86_64 / arm64
- Node.jsとCorepack
- `curl`、`tar`、`xxd`
- USB接続したRP2040 boardを扱える環境
- WebHID確認用のChromium系browser

Versionはrepository側で固定しています。

| Tool / dependency | Version source |
| --- | --- |
| pnpm | root `package.json`の`packageManager` |
| Arduino CLI | `scripts/setup-dev-env.sh` |
| RP2040 Arduino core | `scripts/setup-dev-env.sh` |
| Arduino libraries | `scripts/setup-dev-env.sh` |

## Setup

```sh
scripts/setup-dev-env.sh
```

このscriptはArduino CLIを`.tools/bin/`、Arduino data / downloads / user directoryを`.arduino/`へ配置し、pnpm dependenciesをinstallします。system-wide installは不要です。

Options:

```sh
scripts/setup-dev-env.sh --verify     # setup後にWebとfirmwareをbuild
scripts/setup-dev-env.sh --skip-pnpm  # pnpm installを省略
```

`ARDUINO_CLI_VERSION`と`RP2040_CORE_VERSION`は環境変数でoverrideできます。

## Commands

| Command | Output / purpose |
| --- | --- |
| `pnpm dev` | Vite dev serverを全interfaceで起動 |
| `pnpm typecheck` | Web TypeScriptをemitなしで検査 |
| `pnpm build` | typecheck後に`apps/web/dist`を生成 |
| `pnpm preview` | production buildをlocal preview |
| `pnpm hardware:generate` | profile由来のfirmware / Web / pinout生成 |
| `pnpm firmware:build` | Arduino firmwareをcompile |
| `pnpm firmware:web` | UF2と`RESCUE.CMD`をWeb public assetsへ出力 |
| `pnpm rescue-cmd:assets` | `rescue.cmd`からC headerだけを再生成 |

## Development Workflows

### Web-only Change

```sh
pnpm typecheck
pnpm build
```

画面を確認する場合は`pnpm dev`を起動します。ViteはHome、Start Guide、Build Guide、Remapper、Diagnosticsと非リンクのA6印刷ページの6 entryを扱います。

### Hardware Profile Change

1. `hardware/octgear/profile.json`を編集します。
2. `pnpm hardware:generate`を実行します。
3. 3つの生成物をdiffで確認します。
4. `pnpm build`と`pnpm firmware:build`を実行します。

生成対象:

```text
firmware/octgear/octgear/generated_hardware_config.h
apps/web/src/products/octgear/generatedHardwareConfig.ts
hardware/octgear/pinout.md
```

Firmware build scriptもgeneratorを実行しますが、profile変更commitには3つの生成物を含めます。

### Firmware Change

```sh
pnpm firmware:build
```

配信用artifactも更新する変更では次を使います。

```sh
pnpm firmware:web
```

出力される`apps/web/public/firmware/octgear.uf2`と`RESCUE.CMD`はWeb buildへ含まれます。UF2生成完了時刻は`apps/web/src/products/octgear/generatedFirmwareMetadata.ts`へUTCのISO 8601形式で生成され、Updaterでは閲覧端末のlocaleとtime zoneに合わせて表示します。既定boardは`rp2040:rp2040:waveshare_rp2040_zero`、board optionsは`usbstack=tinyusb,freq=125,flash=2097152_65536`です。64KBの予約領域は3-sector Flash journalに必要です。

Build identityは環境変数でoverrideできます。

```sh
USB_VID=0x1234 USB_PID=0x5678 \
USB_MANUFACTURER=Example USB_PRODUCT=OctGear \
pnpm firmware:build
```

VID/PIDを変えた場合、WebHID filterも同時に更新しないとRemapperから接続できません。

### Rescue Script Change

`firmware/octgear/octgear/rescue.cmd`がsourceです。Firmwareに埋め込む`rescue_cmd_asset.h`はbuild時に再生成されます。Web配布物まで同期するには`pnpm firmware:web`を実行します。

## Configuration Ownership

| Value | Edit here | Do not edit directly |
| --- | --- | --- |
| pin / control / layer metadata | `hardware/octgear/profile.json` | generated hardware files |
| debounce / sleep / LED / rescue toggle | firmware `config.h` | generated header |
| USB identity defaults | firmware build scripts | compiled UF2 |
| WebHID accepted identity | Web product definition `products/octgear/product.ts` | transport code |
| HID wire protocol | firmware + Web protocol modules | one side only |
| UI copy | `src/shared/i18n/ja.ts` and `en.ts` | component-local literals |

## Verification Matrix

| Change area | Minimum verification |
| --- | --- |
| Markdown only | links、commands、generated-file warningの目視確認 |
| Web UI / state | `pnpm typecheck`, `pnpm build` |
| Hardware profile | `pnpm hardware:generate`, Web build, firmware build |
| Firmware logic | `pnpm firmware:build`, target boardで実機確認 |
| HID protocol | Web build、firmware build、Remapper connect/read/save、Diagnostics report |
| Storage / rescue | firmware build、実機でrestore / rebootを含む確認 |

現在repositoryには自動unit test suiteがありません。入力timing、USB lifecycle、Flash persistence、BOOTSEL / MSCは実機確認が必要です。

## Deployment

`.github/workflows/deploy-pages.yml`は`main`へのpushまたはmanual dispatchでGitHub Pages artifactをbuildし、`apps/web/dist`をdeployする構成です。Feature branchやPRではdeploy jobを実行しません。

Pages buildではViteの`github-pages` modeが使われ、base pathは`/octgear/`になります。通常buildとdev serverのbase pathは`/`です。

## Review Checklist

- source-of-truthと生成物が同期している
- Webとfirmwareのlayer / control countが一致する
- HID protocol変更が両実装と文書へ反映されている
- 配布対象firmware変更時にUF2も更新されている
- Storage testを通常のread-only検査として誤解させる表現がない
- USB identity変更時にWebHID filterも更新されている

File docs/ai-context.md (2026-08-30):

# AI Context

この文書はAI assistantや新しい開発者がOctGearの変更箇所と領域間契約を短時間で把握するための入口です。値の正本ではなく、現在の構成を案内する索引として使います。正確な値はリンク先のsourceを確認してください。

## Project Snapshot

OctGearはRP2040 Zero互換boardで動く、8キー + ロータリーエンコーダの小型キーボードです。

| Item | Current design |
| --- | --- |
| Physical input | ダイオードなし2 x 4 matrix、Encoder A / Common / B / SW |
| Logical controls | 8 keys + Encoder CCW / CW / SW = 11 |
| Layers | 8。Layer 0は常時有効、既定有効はLayer 0/1 |
| USB | Keyboard HID、Consumer HID、WebHID vendor report。一時起動時のみWebUSB landing page |
| Default identity | `0x2E8A:0x1133`、Manufacturer / Productは`OctGear` |
| Web | React 19 + TypeScript + Vite multi-page app |
| Firmware | RP2040 Arduino core + Adafruit TinyUSB |
| Persistence | External SPI Flashの3-slot journal + CRC。通常Layerは切り替え後10秒、PCBリビジョンやTap Dance判定時間などの設定は変更時に保存 |
| Status LED | GPIO 14のWS2812B 4 pixels、Encoderは右端LED、対応boardでは内蔵LEDへmirror |

## System Map

```text
hardware/octgear/profile.json
        │
        ├─ generate ─> Firmware constants
        ├─ generate ─> Web control metadata
        └─ generate ─> Human-readable pinout

Browser Build Guide / Remapper / Diagnostics
        │  WebHID report ID 3 / fixed 32 bytes
        ▼
RP2040 firmware
        ├─ Keyboard / Consumer HID ─> OS
        ├─ keymap / device settings ─> Flash journal
        └─ layer / animation state ─> WS2812B
```

通常入力はFirmwareだけで完結します。RemapperまたはDiagnosticsのheartbeatが有効な間は、設定中の入力がOSへ漏れないよう通常HID出力を抑止し、物理入力を`KeyEvent`としてWebへ送ります。

## Canonical Sources

| Information | Canonical source | Derived or related files |
| --- | --- | --- |
| Pin、control順、layer、LED profile | `hardware/octgear/profile.json` | generated C++ / TypeScript / pinout |
| Firmware timingと手動設定 | `firmware/octgear/octgear/config.h` | Firmware behavior |
| Default keymap | `firmware/octgear/octgear/keymap.cpp` | Firmware README |
| HID commandsとpayload | Firmware `hid_reports.h` + handler、Web protocol | `docs/hid-report.md` |
| Web product routes / assets / device identity / UF2 | `apps/web/src/products/octgear/product.ts` | Firmware build identity、README |
| Japanese / English UI copy | `apps/web/src/shared/i18n/ja.ts`, `en.ts` | React components |
| Rescue commands | `firmware/octgear/octgear/rescue.cmd` | generated header、UF2 bundle |

`generated_hardware_config.h`、`generatedHardwareConfig.ts`、`pinout.md`は生成物です。直接編集しません。

## Runtime Modes

### Normal

Scannerは保存済みPCBリビジョンに対応するmatrix pinを使用します。

Scannerがmatrixとencoderを読み、active layerのassignmentをKeyboard / Consumer reportへ変換します。Layer変更は有効なlayerだけを対象にします。通常のLayer変更は最後の切り替えから10秒後にFlashへ保存され、次回起動時に復元されます。Momentary Layerは一時状態のため保存しません。

### Remapper / Diagnostics

Webが300 ms間隔でheartbeatを送ります。Firmwareは最後のheartbeatから3000 ms以内を接続中とみなし、通常HID出力を抑止します。Web側はheartbeat送信失敗または700 ms timeoutでsessionを閉じます。

### WebUSB Landing Boot

通常起動中にK1、K5、Encoder SWを1秒間同時押しすると、watchdog scratchへ1回限りのboot flagを書いてwarm rebootします。次の起動はUSB device revisionを`0x0101`へ変更し、Adafruit TinyUSBのWebUSB landing descriptorでRemapper URLを公開してflagを即座に消去します。通常起動のrevisionは`0x0100`です。Windowsのdescriptor cacheを分離しつつ通常HIDとWebHIDは維持し、このbootではK4のRescue判定を抑止します。次回の再起動では通常のUSB構成へ戻ります。

### USB And LED States

LED状態の大きな優先関係は次のとおりです。

1. USBがmount済みかつsuspend中: 外付け・内蔵LEDを消灯
2. USB未mount: LEDテープ方向に従う流れるカラーホイール
3. Rescue boot: 弱い緑
4. Remapper接続直後1秒: カラーホイール
5. 通常: active layer色の全灯／4灯パターンまたは虹色サイクル + 選択された打鍵アニメーション

PCのresume後は現在Layerの表示へ戻ります。Layer表示は全灯、4灯で8 Layerを識別するパターン、4灯を流れる虹色サイクルから選択できます。Layer色とpixelごとの点灯状態は200 ms以内で遷移します。打鍵アニメーションは無効／波紋／フラッシュ／スパーク／打鍵虹色から選択します。波紋／フラッシュ／スパークは現在または切り替え後のLayer色を使い、打鍵虹色は4灯へ異なる虹色を重ねます。

### Rescue

Key 4を押しながらUSB接続すると、その起動だけread-onlyの`OCTGEAR` MSCと115200 baudのSerial rescueを有効にします。通常HIDは出力しません。Serial rescueは全キーマップとdevice設定の表示・変更、storage診断、compile済み既定値への初期化を提供します。

## Cross-System Invariants

- Control indexはK1-K8が`0-7`、Encoder CCW / CW / SWが`8-10`です。
- Layer 0は無効化できません。
- WebHID config reportはreport ID 3、input / outputとも固定32 bytesです。
- 同一transportで同期commandを並列送信しません。
- Layer color `0,0,0`は消灯です。
- Matrixにダイオードがないため、矩形同時押しの曖昧さが解消するまで直前の安定状態を保持します。
- PCBリビジョンはv3（Row 1 = GPIO 2）とv2互換（GPIO 0）だけを許可し、任意GPIOは受け付けません。
- Firmware更新だけでは保存済みkeymapや設定を上書きしません。
- 頒布前のStorageは現行versionだけを読みます。record変更ではversionを更新し、旧設定は初期化します。
- 配布Firmwareのsource変更はWeb同梱UF2と同期します。

## Where To Make Changes

| Goal | Start with | Also inspect |
| --- | --- | --- |
| Remapper UI | `apps/web/src/app/` | Web README、i18n、responsive styles |
| WebHID command | `apps/web/src/features/device/` | Firmware HID handler、protocol doc |
| Key assignment | Web keymap feature | Firmware assignment、storage、protocol |
| Key scan / Encoder | `key_scanner.*` | profile、pinout、実機timing |
| LED behavior | `status_led.*` | `keymap.*`、`config.h`、operations |
| Persistent setting | `keymap.*`, `keymap_storage.*` | Web command、storage migration |
| Hardware pin / count | `hardware/octgear/profile.json` | generatorの3出力 |
| Firmware updater artifact | Firmware source | `pnpm firmware:web`、Web build |
| Rescue command | `rescue.cmd` | generated asset、operations |

## Verification Boundaries

Repositoryには自動unit test suiteがありません。静的検査とcompileは次で行います。

```sh
pnpm typecheck
pnpm build
pnpm firmware:build
```

配布UF2を更新する場合:

```sh
pnpm firmware:web
pnpm build
```

物理matrix、Encoder方向、LED、USB suspend / remote wakeup、Flash persistence、BOOTSEL、MSCはtarget boardで確認します。

## Reading Order

1. [`../README.md`](../README.md): 製品とquick start
2. [`architecture.md`](architecture.md): モジュール境界とruntime flow
3. [`development.md`](development.md): 変更別workflowと検証
4. [`hid-report.md`](hid-report.md): Firmware / Web間protocol
5. [`operations.md`](operations.md): 利用・更新・復旧手順

すべての文書と更新条件は[`index.md`](index.md)にあります。AI agent向けの作業規約は[`../AGENTS.md`](../AGENTS.md)です。

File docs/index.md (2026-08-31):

# Documentation Index

OctGearの文書索引です。目的に合う文書から読み、値を変更するときは記載されたcanonical sourceを確認してください。

## Start By Task

| Task | Read first | Then |
| --- | --- | --- |
| 製品概要・導入 | [`../README.md`](../README.md) | [`operations.md`](operations.md) |
| ビルドガイド変更 | [`../apps/web/README.md`](../apps/web/README.md) | [`development.md`](development.md)、[`../hardware/octgear/README.md`](../hardware/octgear/README.md) |
| Web UI変更 | [`../apps/web/README.md`](../apps/web/README.md) | [`architecture.md`](architecture.md)、[`development.md`](development.md) |
| Firmware変更 | [`../firmware/octgear/README.md`](../firmware/octgear/README.md) | [`architecture.md`](architecture.md)、[`development.md`](development.md) |
| Hardware profile変更 | [`../hardware/octgear/README.md`](../hardware/octgear/README.md) | [`development.md`](development.md) |
| HID protocol変更 | [`hid-report.md`](hid-report.md) | [`architecture.md`](architecture.md) |
| Firmware更新・実機操作 | [`operations.md`](operations.md) | [`development.md`](development.md) |
| AIによるrepository作業 | [`../AGENTS.md`](../AGENTS.md) | [`ai-context.md`](ai-context.md) |

## Core Documents

| Document | Purpose | Update when |
| --- | --- | --- |
| [`../README.md`](../README.md) | 製品概要、features、quick start | 利用者向け機能、主要command、構成が変わる |
| [`architecture.md`](architecture.md) | システム境界、責務、runtime flow | module責務や領域間flowが変わる |
| [`development.md`](development.md) | Setup、build、生成、検証 | command、toolchain、workflowが変わる |
| [`operations.md`](operations.md) | Remapper、Firmware更新、Diagnostics、rescue | 利用手順や実機挙動が変わる |
| [`hid-report.md`](hid-report.md) | WebHID wire protocol | command、payload、現行contractが変わる |
| [`cost-estimate.md`](cost-estimate.md) | 少量頒布時の暫定材料原価、梱包、未計上費用 | 部品、仕入価格、構成、梱包条件が変わる |
| [`print/README.md`](print/README.md) | 頒布物へ同梱する印刷用データと非リンク公開ページ | 同梱案内、公開URL、印刷条件が変わる |
| [`ai-context.md`](ai-context.md) | AI向けproject mapと不変条件 | source ownershipや主要runtime behaviorが変わる |
| [`../AGENTS.md`](../AGENTS.md) | AI agentの作業・検証規約 | repository policyや必須検証が変わる |

## Component Documents

| Document | Scope |
| --- | --- |
| [`../apps/web/README.md`](../apps/web/README.md) | Web entry point、state、device session、layout、localization |
| [`../firmware/octgear/README.md`](../firmware/octgear/README.md) | Firmware features、LED、default keymap、storage、build |
| [`../firmware/octgear/octgear/README.md`](../firmware/octgear/octgear/README.md) | Sketch module、main loop、config constants |
| [`../hardware/octgear/README.md`](../hardware/octgear/README.md) | Hardware profile、生成物、electrical assumptions |
| [`../apps/web/src/shared/README.md`](../apps/web/src/shared/README.md) | Web shared moduleの境界 |

## Generated References

| Document | Generated from | Command |
| --- | --- | --- |
| [`../hardware/octgear/pinout.md`](../hardware/octgear/pinout.md) | `hardware/octgear/profile.json` | `pnpm hardware:generate` |

生成されたC++ / TypeScript設定とpinoutは直接編集しません。Firmware buildでもhardware generatorは実行されますが、profile変更時は3生成物を同じcommitへ含めます。

## Policy And Licensing

| Document | Scope |
| --- | --- |
| [`../LICENSE`](../LICENSE) | Softwareとsoftware documentation |
| [`../HARDWARE-LICENSE.md`](../HARDWARE-LICENSE.md) | `hardware/`以下のdesign materials |
| [`../TRADEMARKS.md`](../TRADEMARKS.md) | 名称、ロゴ、公式性の表示 |

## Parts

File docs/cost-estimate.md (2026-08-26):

# OctGear 原価見積

OctGearを少量頒布する場合の、1台あたりの暫定材料原価です。価格は2026年7月28日時点の購入候補を基にしており、販売価格や将来の仕入価格を保証するものではありません。

## 計算条件

- 1台あたりの使用量で按分する
- ドル建て部品は暫定で`1 USD = 150 JPY`として換算する
- PCBは5枚単位、送料込み`3 USD`で発注する
- ケースとノブはFDMで自家印刷し、塗装しない
- 基本商品はSwitchとKeycapを含まないbareboneとし、両部品は別売にする
- USB Type-Cケーブルは同梱しない
- 表示価格に含まれると明記されていない送料、輸入時の税、決済手数料は含めない
- 作業工賃、工具、3Dプリンターの償却、販売手数料、購入者への送料は含めない

## 1台あたりの材料原価

| 部品 | 購入条件 | 1台の使用量 | 1台あたり |
| --- | ---: | ---: | ---: |
| RP2040-Zero互換board | 1個 `300円` | 1個 | `300.00円` |
| Kailh hot-swap socket | 110個 `1,485円` | 8個 | `108.00円` |
| WS2812B strip、1m / 60 pixels / IP30 | 1本 `606円` | 4 pixels | `40.40円` |
| OctGear PCB | 5枚、送料込み `3 USD` | 1枚 | `0.60 USD` / 約`90.00円` |
| M2 x 8mm screw | 200本 `945円` | 5本 | `23.63円` |
| EC11 rotary encoder、軸高15mm | 5個 `217円` | 1個 | `43.40円` |
| FDM case + knob | Filament 1kg `2,000円` | 約37g + 印刷ロス | 約`90.00円` |
| 1/4 inch mount nut | 20個 `318円` | 1個 | `15.90円` |
| 3M CS-101 cushion rubber | 88粒 `730円` | 4粒 | `33.18円` |
| AWG24相当の配線材 | 使用量按分 | 1台分 | 約`1.00円` |
| Solder | 使用量按分 | 1台分 | 約`1.00円` |
| Packaging case `MJ-SBOX08-S` | 100枚 `4,471円` | 1枚 | `44.71円` |
| **Barebone暫定合計** |  |  | **約`791円`** |

端数を含むbareboneの計算値は約`791.21円`です。印刷ロスを含めないFDM材料費を使う場合は約`775円`ですが、見積では少量のsupport、skirt、purge、失敗分を含めて`90円`としています。

## Product Configurations

頒布時は、SwitchとKeycapを含まないBarebone版と、両部品を含むFull Set版の両方を扱えるようにします。

| Configuration | Included switch / keycap | 材料原価 | 不良・予備5-10%込み |
| --- | --- | ---: | ---: |
| Barebone | なし | 約`791円` | 約`831-870円` |
| Full Set | Outemu Tactile Brown 8個、Keycap 8個 | 約`1,212円` | 約`1,273-1,333円` |

どちらにもOctGear本体、Case、Knob、クッションゴム、mount nut、梱包箱を含みます。USB Type-C cableは含みません。

## Optional Switch And Keycap Set

SwitchとKeycapはbareboneに含めず、利用者が用意するか、別売setとして追加できる構成にします。

| 部品 | 購入条件 | 1setの使用量 | 1setあたり |
| --- | ---: | ---: | ---: |
| Outemu Tactile Brown switch | 110個 `1,469円` | 8個 | `106.84円` |
| Keycap | 20個 `785円` | 8個 | `314.00円` |
| **別売set材料原価** |  |  | **約`421円`** |

Bareboneへこのsetを加えた場合の材料原価は約`1,212円 / 台`です。別売価格には、set用の袋、label、在庫ロス、販売手数料を別途加算します。

## FDM Case

見積に使用したSTL体積は次のとおりです。

| Part | Volume |
| --- | ---: |
| `octgear-encoder-knob.stl` | `2.44 cm³` |
| `octgear-case-top.stl` | `12.63 cm³` |
| `octgear-case-bottom.stl` | `13.20 cm³` |
| `octgear-led-diffuser.stl` | `1.18 cm³` |
| **Total** | **`29.47 cm³`** |

PLAの密度を`1.24 g/cm³`とすると、100%充填相当で約`37g`、材料費は約`74円`です。実際の使用量はwall、infill、support、skirtなどのslicer設定で変わるため、量産条件を決めた後はslicer表示の重量へ置き換えます。

LED拡散部品はLEDの光を拡散させるため、NaturalまたはTranslucentのPLA / PETGを使用します。ケース上面、底面、ノブと異なるfilamentを使う場合、1台あたりの消費原価とは別に複数spoolの初期購入費が必要です。`octgear-rubber-foot-fixing-jig.stl`の体積は`3.95 cm³`ですが、製品へ組み込まない製造治具のため1台あたりの材料原価には含めません。

## Packaging

完成時の実測寸法はおよそ`120 x 60.5 x 28 mm`です。

`MJ-SBOX08-S`の内寸は`157 x 117 x 41 mm`、外寸は`160 x 125 x 45 mm`です。完成品は収納できますが、外寸の厚さが45mmあるため、厚さ30mm以下の配送方法には使用できません。

半組み立てキットではKeycap、Knob、Switch、Caseを分けて平置きし、外寸30mm以下の梱包を検討します。箱材と緩衝分を考慮し、内容物の最大高さは`24-26mm`を目安にします。3cm梱包箱と薄型緩衝材の価格は未計上です。

## Reserve And Excluded Costs

材料原価へ5-10%の不良・予備分を加えると、Bareboneは約`831-870円 / 台`、Full Setは約`1,273-1,333円 / 台`です。販売価格を決めるときは、さらに次を別枠で加算します。

- 仕入先ごとの未計上送料、輸入時の税、為替・決済手数料
- FDM印刷の電気代、失敗、printer maintenance
- 組み立て、Firmware書き込み、動作検査、梱包の作業工賃
- 説明card、薄型緩衝材、label
- BOOTH等の販売手数料
- 購入者への送料
- 初期不良交換と問い合わせ対応のreserve

## Items To Confirm

- `Y809-0114`は`1/4 x 20山`表記だが、camera / tripod mountで使う`1/4-20 UNC`との規格一致を実物で確認する
- 半組み立て用3cm梱包箱の品番、単価、梱包後の実測厚を確定する
- 各購入価格が送料・税を含むか、実際のcard請求額で更新する
- 量産用slicer profileを決め、Case + Knobの実使用重量と印刷時間を測定する

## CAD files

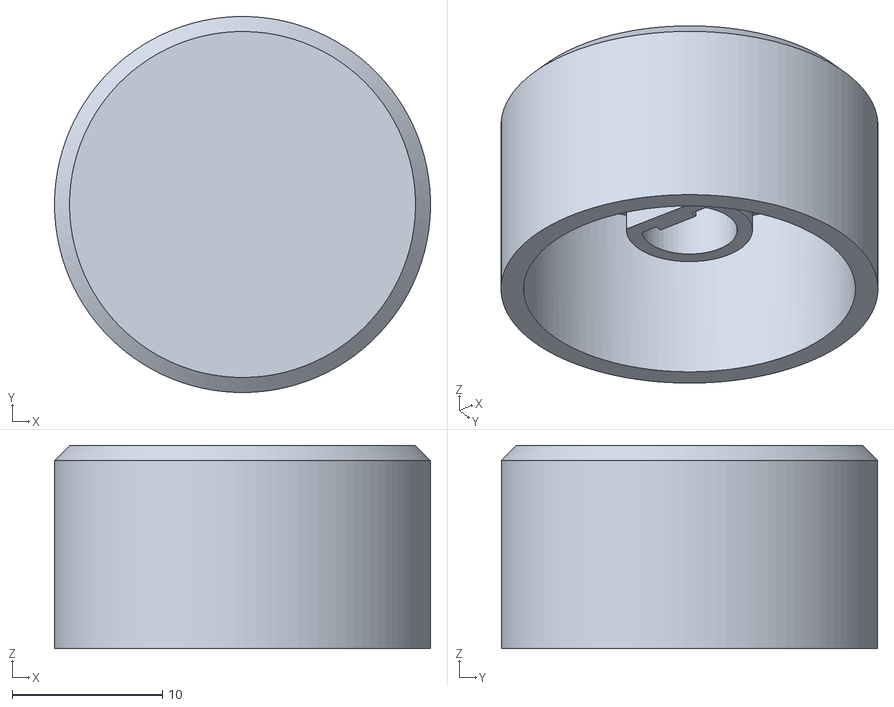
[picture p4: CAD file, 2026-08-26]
apps/web/public/build-guide/downloads/octgear-encoder-knob.stl
25.0 x 25.0 x 13.5

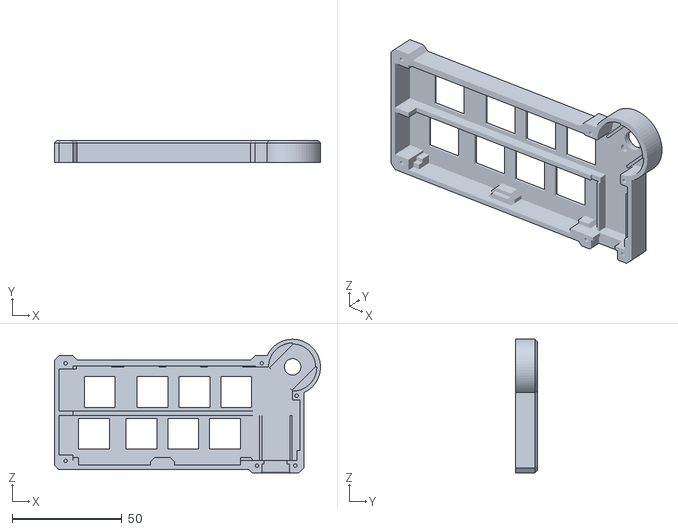
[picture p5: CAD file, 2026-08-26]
apps/web/public/build-guide/downloads/octgear-case-top.stl
121.2 x 9.90 x 60.9

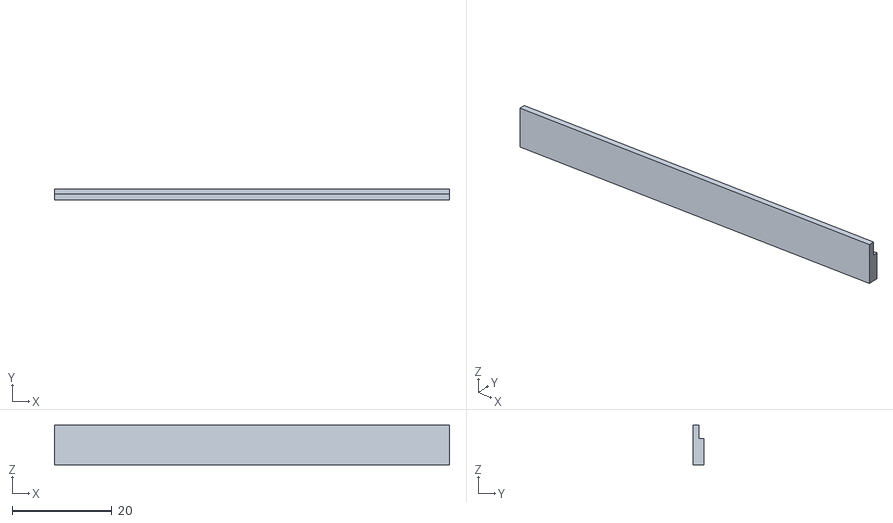
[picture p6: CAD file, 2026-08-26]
apps/web/public/build-guide/downloads/octgear-led-diffuser.stl
79.1 x 2.20 x 8.00

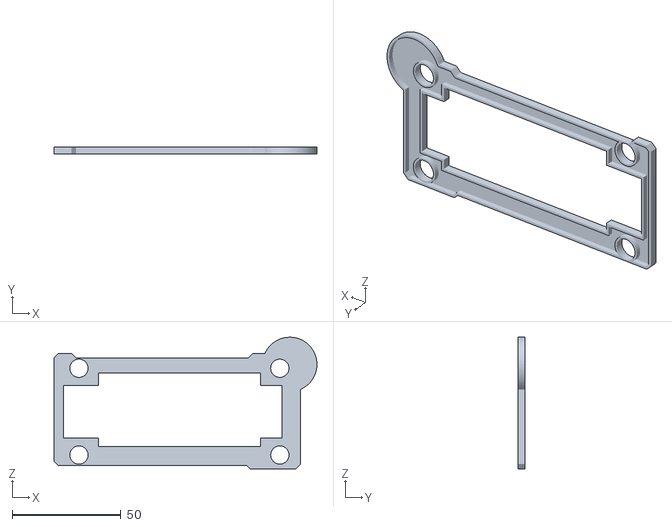
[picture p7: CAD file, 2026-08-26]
apps/web/public/build-guide/downloads/octgear-rubber-foot-fixing-jig.stl
120.8 x 3.00 x 60.5

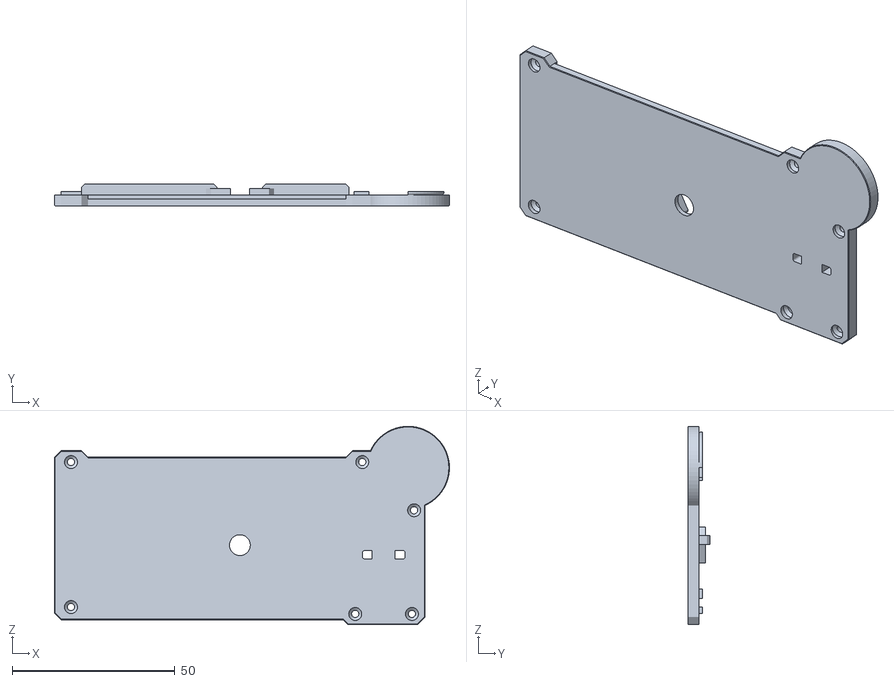
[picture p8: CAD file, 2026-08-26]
apps/web/public/build-guide/downloads/octgear-case-bottom.stl
121.2 x 6.80 x 60.9

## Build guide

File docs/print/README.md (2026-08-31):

# Print Materials

頒布物へ同梱する印刷用データです。A6カードはGitHub Pagesへ公開しますが、Homeや各ツールからはリンクせず、検索避けの`noindex`を設定します。URLを知っていれば誰でも閲覧できるため、秘密情報は掲載しません。

## OctGear Start Guide Card

印刷用の[`octgear-start-guide-a6.pdf`](../../apps/web/public/print/octgear-start-guide-a6.pdf)はA6縦・1ページで生成済みです。[`octgear-start-card-a6.html`](../../apps/web/octgear-start-card-a6.html)が編集用sourceです。

公開先:

- HTML: `https://studio-juh.github.io/octgear/octgear-start-card-a6.html`
- PDF: `https://studio-juh.github.io/octgear/print/octgear-start-guide-a6.pdf`

HTMLからPDFを再生成または直接印刷する場合は、browserで開いて次の条件を使用します。

- 用紙: A6
- 向き: 縦
- 倍率: 100%
- 余白: なし
- ヘッダーとフッター: なし
- 背景のグラフィック: 有効

QRコードと印刷されたURLが`https://studio-juh.github.io/octgear/octgear-start.html`を開くことを、入稿・印刷前に実機で確認してください。

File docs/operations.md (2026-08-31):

# Operations

通常のキーマップ設定、firmware更新、出荷検査、offline rescueの手順です。

## Remapper

RemapperはWebHIDでOctGearへ接続します。Web Serialは使いません。

PCとタブレットでは、画面上部の「表示倍率」でWorkspaceを`80%`、`90%`、`100%`へ切り替えられます。既定値は`90%`です。選択した倍率はbrowserへ保存され、次回も引き継がれます。表示が収まりきらない場合は`80%`、文字や操作部を大きくしたい場合は`100%`を選択してください。スマートフォン幅では操作部の大きさを保つため、自動的に`100%`表示になります。

### Open From Device

通常起動中にK1、K5、Encoder SWを同時に1秒間押し続けると、LEDが水色に200 ms点灯してOctGearが再起動します。再起動後の1回だけWebUSB landing pageが有効になり、対応するdesktop ChromiumではUSB deviceの接続通知から`https://studio-juh.github.io/octgear/octgear-remapper.html`を開けます。案内modeでも通常HIDとWebHIDは利用できます。Windowsが通常起動時のdescriptor不在を再利用しないよう、この起動だけUSB device revisionを`0x0101`へ変更し、通常起動では`0x0100`へ戻します。

これは毎回のUSB接続で表示される機能ではありません。案内modeの起動時だけ有効で、通知を自動的に操作したりbrowserを強制的に開いたりはしません。OSやbrowserが通知に対応していない場合はURLを直接開いてください。USBを抜き差しするか再起動すると、次回は通常のUSB構成へ戻ります。

### Connect And Edit

1. OctGearを通常起動でUSB接続します。
2. `/octgear-remapper.html`をChromium系browserで開きます。
3. Connectから`OctGear`を選択します。
4. 接続時に全layer / controlのkeymapが読み込まれます。
5. layerとcontrolを選び、割り当てを編集します。
6. Layer 1-7は各checkboxで有効／無効を選びます。初期状態ではLayer 0/1が有効です。
7. 選択LayerのLED色をswatchまたはR/G/Bで設定します。点灯checkboxを外すと消灯します。
8. Saveで、最後に読み込んだ内容との差分だけをdeviceへ書き込みます。

Readはdeviceから全keymapとlayer設定を再読込し、未保存の編集内容を置き換えます。Saveは全layer / controlを比較しますが、変更がない設定へのFlash writeは行いません。Layer 0は安全なbase layerとして常に有効です。

Hardware cardの「設定を開く」からHardware設定モーダルを開きます。モーダル上部にはBoard詳細、その下には変更可能な設定を表示します。「回転方向 / 反転」はEncoderのCCW/CWを入れ替え、変更時に実機へ即座に保存します。

Hardware設定モーダルの「PCBリビジョン」は、現行PCB v3のRow 1 = GPIO 2と旧PCB v2のRow 1 = GPIO 0を切り替えます。基板に記載されたrevisionへ合わせてください。変更は即座に保存・適用され、再起動は不要です。任意GPIOの指定はできません。

Hardware設定モーダルの「LEDテープ方向 / 反転」は、盤面左端のLED 1をphysical pixel 0へ対応させる標準順と、最後のphysical pixelへ対応させる反転順を切り替え、変更時に実機へ即座に保存します。位置依存の打鍵アニメーションとUSB未認識時の流れるアニメーションの向きに適用されます。

Hardware設定モーダルの「レイヤー表示」は、Layer色による全灯、4灯の点灯パターン、虹色サイクルを切り替えます。4灯パターンでは点灯pixelに現在Layerの色を使い、消灯pixelを含めてLayer切り替え時に200 msで遷移します。虹色サイクルではLayer色の代わりに4灯へ異なる色相を表示して流します。設定は変更時にFlashへ即座に保存されます。

| Firmware Layer | 操作上の順番 | LED 1 → LED 4 |
| ---: | ---: | --- |
| 0 | 1 | `1000` |
| 1 | 2 | `0100` |
| 2 | 3 | `0010` |
| 3 | 4 | `0001` |
| 4 | 5 | `0111` |
| 5 | 6 | `1011` |
| 6 | 7 | `1101` |
| 7 | 8 | `1110` |

Hardware設定モーダルの「アニメーション効果」は、打鍵表示を無効／波紋／フラッシュ／スパーク／打鍵虹色から選ぶプルダウンです。変更時に実機へ即座に保存します。波紋は押下位置から左右へ広がり、フラッシュは4灯を同時点灯、スパークは押下位置とその周囲を短く光らせます。打鍵虹色は4灯へ異なる色相を表示し、押すたびに開始色相を変えながら320 msで通常表示へ戻ります。通常の3効果は現在または切り替え後のLayer色で発光します。EncoderのCCW / CW / SWは右端のLED 4をK4 / K8と共有します。

Hardware設定モーダルの「アニメーション輝度上限」は`0-128`で設定し、「適用」でFlashへ保存します。Layer側の「LED輝度上限」より高くすると、アニメーション対象pixelだけが明るくなりコントラストが強まります。既定値は`96`、`0`ではハイライトを消します。

Hardware設定モーダルの「LED輝度上限」は`0-128`で設定します。`0`は消灯です。Sliderまたは数値を変更し、「適用」で外付けWS2812Bと内蔵mirrorへ反映してFlashへ保存します。既定値は`32`です。

PCがスリープしてUSBがサスペンド状態になると、外付けLEDと内蔵LEDは消灯します。PCの復帰後は現在Layerの色へ戻ります。USB未認識で電源だけが接続されている場合は、従来どおり流れるカラーホイールを表示します。

初期キーマップはLayer 0/1だけに割り当てがあり、Layer 2〜7は空です。Firmwareを更新しただけでは保存済み設定を上書きしません。初期値へ戻す場合はRemapperのRead左側にあるメニューから初期化します。

Next Layer、Previous Layer、Remapper、Serial rescueで通常Layerを切り替えると、最後の切り替えから10秒後に現在LayerをFlashへ自動保存します。10秒以内の連続切り替えは1回の保存へまとめられ、次回起動時は保存したLayerから始まります。Next Layerは最初の押下をTap Dance判定時間だけ保留し、単押しなら次へ進みます。同じ物理controlを期限内にもう一度押すとNextを実行せず、開始LayerからPrevious Layerとして一つ前へ進みます。判定時間はRemapperのHardwareから50-1000 msで設定でき、既定値は250 msです。Momentary Layerは押している間だけの一時状態なので保存しません。

物理キーやencoderを操作すると、対応するcontrol tileが選択されます。接続中はheartbeatにより通常のKeyboard / Consumer出力がfirmware側で抑止されるため、設定操作がPC入力として流れません。

### Assignment Types

| Type | Behavior |
| --- | --- |
| None | 出力しない |
| Keyboard | 押下中assignmentのmodifierと最大6種類のkeycodeを統合して送る |
| Consumer | 最後に押された押下中のvolume、media等の16-bit usageを送る |
| Next Layer | 単押しは設定した判定時間後に次へ、同じcontrolのダブルタップは開始位置から前へ切り替える |
| Previous Layer | 有効なlayerだけを前方向へ切り替える |
| Momentary Layer | target layerが有効な場合、押している間だけ切り替える |

## Firmware Update

Remapperのfirmware panelには、BOOTSEL移行、同梱UF2 download、browserからのUF2書込があります。

### Browser Write

1. OctGearへWebHID接続します。
2. BOOTSELへの切替を実行します。
3. OSに`RPI-RP2`またはUF2 bootloader driveが現れるのを待ちます。
4. Browserのfolder pickerでそのdriveを選びます。
5. 同梱`octgear.uf2`の書込完了を待ちます。

Folder pickerによる直接書込はFile System Access APIが必要です。未対応browserではUF2をdownloadし、OS上でbootloader driveへcopyしてください。

WebHIDからBOOTSELへ移行できない場合は、boardのBOOTSEL操作を使って手動でbootloader driveを表示します。

完成品では底面に並ぶ2つの小穴からboard上のbuttonを操作できます。底面を正面に見て左側の穴がBOOT、右側がRESETです。USB接続中に左側からBOOTを押したまま、右側からRESETを押して離し、最後にBOOTを離すとbootloaderへ移行します。buttonは爪楊枝など電気を通さない細い物で静かに押してください。針、ピン、精密ドライバーなど金属製の針状工具は、内部を短絡・損傷するおそれがあるため使用しないでください。

## Diagnostics

`/octgear-diagnostics.html`は出荷前・販売前の個体検査用です。

検査項目:

- BrowserのWebHID support
- OctGearへの接続
- 物理キー8個、Encoder CCW / CW / SWのevent
- Encoder CCW / CWの累積検出回数
- Vendor reportのrequest / response
- Firmware-reported layer / key count
- Keymap storageのwrite / read / restore

### Recommended Order

1. Connectして、firmwareが`keyCount = 11`を返すことを確認します。
2. 8キーとencoder 3操作をそれぞれ入力し、全controlが記録されることを確認します。
3. Reset後、Encoderを各方向へゆっくり20ノッチ回し、CCW / CW counterがそれぞれ20増えることを確認します。
4. Diagnostic report testを実行します。
5. 必要な個体だけStorage testを実行します。
6. Disconnectして通常HID入力へ戻ることを確認します。

Diagnostic report testは固定nonceを送り、`RPT` signature、protocol version、echoを検証します。

> Storage testは実際のFlash-backed keymap保存領域へtest patternを書きます。検証後に元のkeymapを復元しますが、書込回数を伴うため、必要な検査時だけ実行してください。電源断やUSB切断をtest中に行わないでください。

## Rescue Boot

WebHIDを利用できない場合、Key 4 bootでoffline rescueを起動できます。

1. OctGearをUSBから外します。
2. Key 4を押したままUSB接続します。
3. LEDが弱い緑になり、read-onlyの`OCTGEAR` driveが現れるまで待ちます。
4. Windowsでは`RESCUE.CMD`を実行します。
5. `help`でcommand一覧を確認します。
6. 終了後はUSBを抜き、キーを押さずに再接続します。

Driveには`README.TXT`、`READMEEN.TXT`、Remapperへ直接開く`REMAPPER.URL`、`RESCUE.CMD`が含まれます。Serialは115200 baud、8-N-1、LF終端です。`RESCUE.CMD`は現行USB identityの`0x2E8A:0x1133`または`OCTGEAR ACK`を返すportを自動検出し、見つからない場合は手動選択へ移ります。

## Serial Rescue Commands

Layerは`0-7`、key番号は`1-11`です。数値はdecimalまたは`0x`付きhexを受け付けます。

| Command | Purpose | Persists |
| --- | --- | --- |
| `probe` | OctGear rescue identityとcountを返す | No |
| `help` / `?` | command一覧 | No |
| `state` | Layer状態、全device設定、全Layer色を表示 | No |
| `dump` | `state`の内容と全assignmentを表示 | No |
| `layer <layer>` | active layerを変更 | 10秒後 |
| `get <layer> <key>` | assignmentを表示 | No |
| `none <layer> <key>` | assignmentを消去 | Yes |
| `key <layer> <key> <modifier> <keycode...>` | Keyboard assignmentを設定 | Yes |
| `consumer <layer> <key> <usage>` | Consumer assignmentを設定 | Yes |
| `cycle <layer> <key>` | Layer Cycleを設定 | Yes |
| `back <layer> <key>` | Previous Layerを設定 | Yes |
| `hold <layer> <key> <target>` | Momentary Layerを設定 | Yes |
| `color <layer> <red> <green> <blue>` | Layer LED色を設定。`0 0 0`で消灯 | Yes |
| `enabled <layer> <0\|1>` | Layerを無効／有効にする。Layer 0は無効化不可 | Yes |
| `encoder-reversed <0\|1>` | Encoder回転方向を標準／反転にする | Yes |
| `pcb-revision <2\|3>` | Matrix Row 1を旧PCBのGPIO 0／現行PCBのGPIO 2へ切り替える | Yes |
| `led-reversed <0\|1>` | 外付けLEDのphysical pixel順を標準／反転にする | Yes |
| `led-brightness <0-128>` | Layer表示の輝度上限を設定 | Yes |
| `animation <0-4>` | 打鍵効果を波紋／無効／フラッシュ／スパーク／打鍵虹色に設定 | Yes |
| `animation-brightness <0-128>` | 打鍵アニメーションの輝度上限を設定 | Yes |
| `layer-display <0-2>` | Layer表示を全灯／4灯パターン／虹色サイクルに設定 | Yes |
| `tap-dance <50-1000>` | Layer Tap Dance判定時間をmsで設定 | Yes |
| `reset confirm` | 全キーマップとdevice設定をcompile済み既定値へ戻す | Yes |
| `diag` | Storage self-testを実行 | Test writes |
| `bootloader` | UF2 bootloaderへ再起動 | No |

Examples:

```text
state
get 0 1
key 1 1 0x00 0x04
key 1 2 0x01 0x06
consumer 0 1 0x00e2
cycle 0 8
back 0 7
hold 0 5 2
color 0 32 160 255
color 7 0 0 0
enabled 2 1
encoder-reversed 1
pcb-revision 3
led-reversed 0
led-brightness 32
animation 0
animation-brightness 96
layer-display 1
tap-dance 250
```

`animation`は`0`が波紋、`1`が無効、`2`がフラッシュ、`3`がスパーク、`4`が打鍵虹色です。`layer-display`は`0`が全灯、`1`が4灯パターン、`2`が虹色サイクルです。`pcb-revision`は`2`または`3`だけを受け付けます。boolean設定は`0`が標準／無効、`1`が反転／有効です。

Keyboard modifier bitmap:

| Bit | Modifier |
| ---: | --- |
| `0x01` | Left Ctrl |
| `0x02` | Left Shift |
| `0x04` | Left Alt |
| `0x08` | Left GUI |
| `0x10` | Right Ctrl |
| `0x20` | Right Shift |
| `0x40` | Right Alt |
| `0x80` | Right GUI |

設定変更commandは成功時に設定全体を即座にFlashへ保存します。`reset`は誤操作を避けるため、必ず`reset confirm`と入力します。保存に失敗した場合はRAM上の値も変更前へ戻します。`diag`はWeb DiagnosticsのStorage testと同じ保存領域を検査します。

## Troubleshooting

| Symptom | Check |
| --- | --- |
| Device pickerにOctGearがない | 対応browser、HTTPS / localhost、USB cable、VID/PIDを確認 |
| 接続直後に切断表示になる | heartbeat timeout、device再起動、別tabの接続を確認 |
| Remapper接続中に通常キーが出ない | 設計どおり。Disconnectすると通常出力へ戻る |
| Encoder方向が違う | Remapperの「回転方向 / 反転」を切り替える |
| K1-K4だけ反応しない | 基板revisionを確認し、Remapperの「PCBリビジョン」をv2またはv3へ合わせる |
| 打鍵アニメーションの左右が逆 | Remapperの「LEDテープ方向 / 反転」を切り替える |
| Encoderのdetent数が違う | profileの`stepsPerDetent`を確認して再build |
| UF2 driveへ直接書けない | UF2をdownloadしてOSからcopy |
| `OCTGEAR` driveが出ない | USB接続前からKey 4を保持しているか確認 |
| WebUSBの接続通知が出ない | desktop Chromiumの通知対応を確認し、出ない場合はRemapper URLを直接開く |
| Rescue portを自動検出できない | OSのserial port権限とmanual selectionを確認 |

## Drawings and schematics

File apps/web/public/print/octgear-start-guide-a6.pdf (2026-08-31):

# OctGear

# はじめに

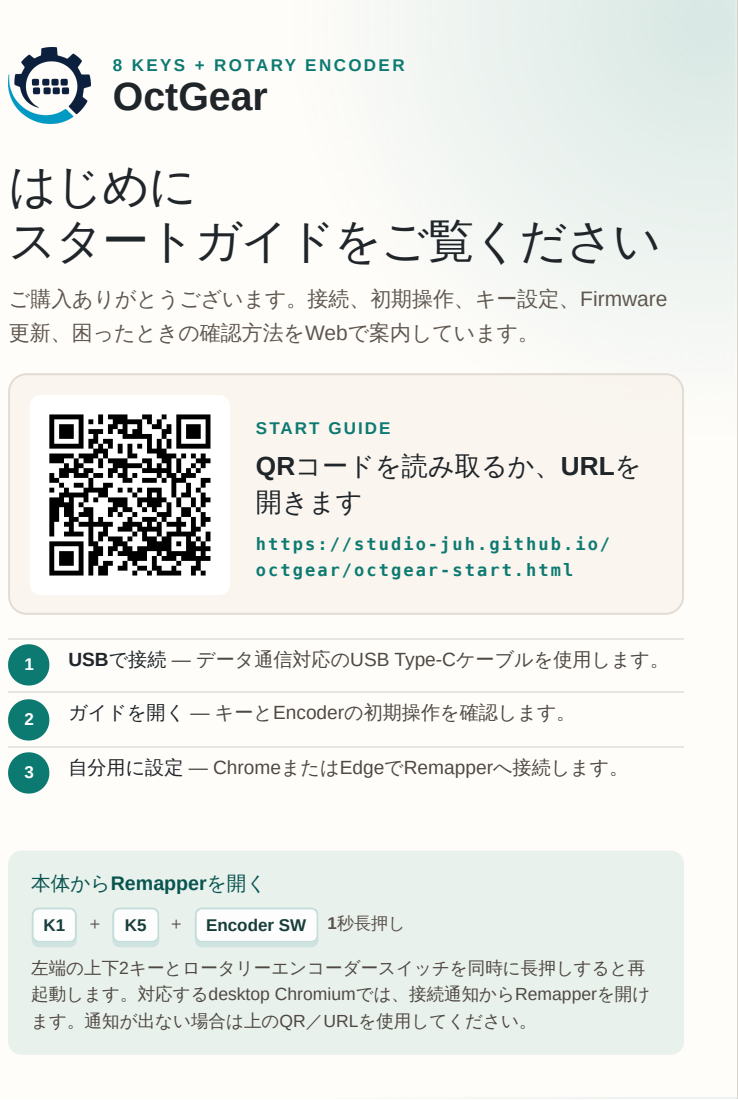
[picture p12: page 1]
スタートガイドをご覧ください; START GUIDE QRコードを読み取るか、URLを 開きます; 本体からRemapperを開く; Encoder SW; 1秒長押し; 2 ガイドを開く — キーとEncoderの初期操作を確認します。; 3 自分用に設定 — ChromeまたはEdgeでRemapperへ接続します。

8 KEYS + ROTARY ENCODER

ご購入ありがとうございます。接続、初期操作、キー設定、Firmware
更新、困ったときの確認方法をWebで案内しています。

https://studio-juh.github.io/
octgear/octgear-start.html

1 USBで接続 — データ通信対応のUSB Type-Cケーブルを使用します。

左端の上下2キーとロータリーエンコーダースイッチを同時に長押しすると再
起動します。対応するdesktop Chromiumでは、接続通知からRemapperを開け
ます。通知が出ない場合は上のQR／URLを使用してください。

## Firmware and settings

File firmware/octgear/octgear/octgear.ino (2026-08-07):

#include "hid_device.h"
#include "config.h"
#include "key_scanner.h"
#include "keymap.h"
#include "keymap_storage.h"
#include "readme_drive.h"
#include "serial_rescue.h"
#include "status_led.h"
#include "webusb_landing.h"

#if defined(ARDUINO_ARCH_RP2040)
#include "pico/time.h"
#endif

namespace {

void sleepBetweenScans(bool remapperActive) {
#if defined(ARDUINO_ARCH_RP2040)
  sleep_us(remapperActive ? Config::REMAPPER_SCAN_SLEEP_US : Config::IDLE_SCAN_SLEEP_US);
#else
  (void)remapperActive;
#endif
}

}  // namespace

void setup() {
  beginKeymap();
  beginStatusLed();
  beginKeyScanner();
  const bool landingBoot = beginWebUsbLanding();
  const bool rescueBoot = !landingBoot && readmeDriveRequestedAtBoot();
  if (rescueBoot) {
    beginSerialRescue();
  }
  beginHidDevice();
}

void loop() {
  const bool remapperActive = remapperConnected();
  const bool readmeActive = readmeDriveActive();
  const bool rescueActive = readmeActive && serialRescueActive();
  const bool rescueIndicatorActive = readmeActive || rescueActive;
  const bool configActive = remapperActive || rescueIndicatorActive;

  const bool scannerChanged = updateKeyScanner(!configActive);
  const bool landingShortcutActive =
    !rescueIndicatorActive &&
    updateWebUsbLandingShortcut(currentKeyMask());

  if (landingShortcutActive) {
    cancelHidInputForSystemShortcut();
  } else if (scannerChanged && !rescueIndicatorActive) {
    const Config::KeyMask previousMask = previousKeyMask();
    const Config::KeyMask currentMask = currentKeyMask();
    sendKeyChanges(previousMask, currentMask, activeLayer());
  }

  updateHidDevice();
  updateKeymapStorage();
  if (readmeActive) {
    updateSerialRescue();
  }
  updateStatusHeartbeat(
    hidDeviceMounted(),
    hidDeviceSuspended(),
    remapperActive,
    rescueIndicatorActive,
    activeLayer()
  );
  sleepBetweenScans(configActive);
}

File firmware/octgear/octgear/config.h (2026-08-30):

#pragma once

#include <Arduino.h>
#include "generated_hardware_config.h"

namespace Config {

constexpr uint8_t KEYBOARD_REPORT_SLOTS = 6;
constexpr uint8_t CONFIG_REPORT_SIZE = 32;

constexpr uint8_t STATUS_LED_PIN = EXTERNAL_RGB_LED_PIN;
constexpr uint8_t STATUS_RESCUE_GREEN = 18;

constexpr uint16_t DEBOUNCE_US = 5000;
constexpr uint16_t IDLE_SCAN_SLEEP_US = 100;
constexpr uint16_t REMAPPER_SCAN_SLEEP_US = 1000;
constexpr uint16_t DEFAULT_LAYER_TAP_DANCE_TERM_MS = 250;
constexpr uint16_t MIN_LAYER_TAP_DANCE_TERM_MS = 50;
constexpr uint16_t MAX_LAYER_TAP_DANCE_TERM_MS = 1000;
constexpr uint16_t STATUS_COLOR_WHEEL_MS = 40;
constexpr uint16_t STATUS_LAYER_TRANSITION_MS = 200;
constexpr uint16_t STATUS_LED_FRAME_MS = 20;
constexpr uint16_t STATUS_KEY_RIPPLE_STEP_MS = 45;
constexpr uint16_t STATUS_KEY_RIPPLE_PULSE_MS = 160;
constexpr uint16_t STATUS_KEY_FLASH_MS = 180;
constexpr uint16_t STATUS_KEY_SPARK_MS = 240;
constexpr uint16_t STATUS_KEY_RAINBOW_MS = 320;
constexpr uint8_t STATUS_KEY_ANIMATION_SLOTS = 8;
constexpr uint16_t STATUS_REMAPPER_ANIMATION_MS = 1000;
constexpr uint16_t REMAPPER_HEARTBEAT_TIMEOUT_MS = 3000;
constexpr uint32_t ACTIVE_LAYER_SAVE_DELAY_MS = 10000;
constexpr uint16_t WEBUSB_LANDING_HOLD_MS = 1000;
constexpr uint16_t WEBUSB_LANDING_ACK_MS = 200;
constexpr uint16_t WEBUSB_LANDING_DEVICE_VERSION = 0x0101;
constexpr uint8_t CONFIG_RESPONSE_READY_RETRIES = 20;
constexpr uint16_t CONFIG_RESPONSE_RETRY_DELAY_US = 100;

constexpr bool README_DRIVE_ENABLED = false;
constexpr uint8_t README_DRIVE_ENABLE_KEY_INDEX = 3;
constexpr const char* REMAPPER_URL =
  "https://studio-juh.github.io/octgear/octgear-remapper.html";
constexpr uint8_t WEBUSB_LANDING_KEY_1_INDEX = 0;
constexpr uint8_t WEBUSB_LANDING_KEY_2_INDEX = 4;

}  // namespace Config

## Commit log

2026-07-25 Animate firmware status LED states
2026-07-25 Add reactive LED effects and strip direction
2026-07-25 Add selectable key LED animations
2026-07-26 Turn off LEDs during USB suspend
2026-07-26 Add manufacturing assets and STL viewer
    [octgear-case-bottom.stl, octgear-case-middle.stl, octgear-case-top.stl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]
2026-07-27 Add persistent language switcher
2026-07-28 Move build guide language switch to header
2026-07-28 Expand build guide assembly instructions
2026-07-28 Update OctGear case design assets
    [octgear-case-bottom.stl, octgear-case-middle.stl, octgear-case-top.stl]
2026-08-04 Update OctGear to four status LEDs
2026-08-04 Fix layer tap dance direction
    [hid_device.cpp]
2026-08-07 Harden encoder decoding and diagnostics
2026-08-07 Add optional LED layer patterns
2026-08-07 Fix save and reset preview clearing
    [hid_device.cpp]
2026-08-07 Add one-shot WebUSB landing mode
2026-08-07 Separate WebUSB landing device revision
2026-08-07 Update serial rescue for current settings
2026-08-26 feat: complete OctGear assembly guide
2026-08-26 feat: update OctGear case models
    [octgear-case-bottom.stl, octgear-case-middle.stl, octgear-case-top.stl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]
2026-08-26 feat: update PCB row pin to GPIO 2
2026-08-26 feat: add selectable PCB revision
2026-08-26 feat: update OctGear top and knob models
    [octgear-case-top.stl, octgear-encoder-knob.stl]
2026-08-26 docs: add mounting nut assembly step
2026-08-26 fix(firmware): animate keys with layer color
    [status_led.cpp]
2026-08-30 Add rainbow LED effects
